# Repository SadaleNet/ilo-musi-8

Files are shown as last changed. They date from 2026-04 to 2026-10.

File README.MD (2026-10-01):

**(English: Scroll down for English | toki ike Inli li lon anpa pi toki pona)**

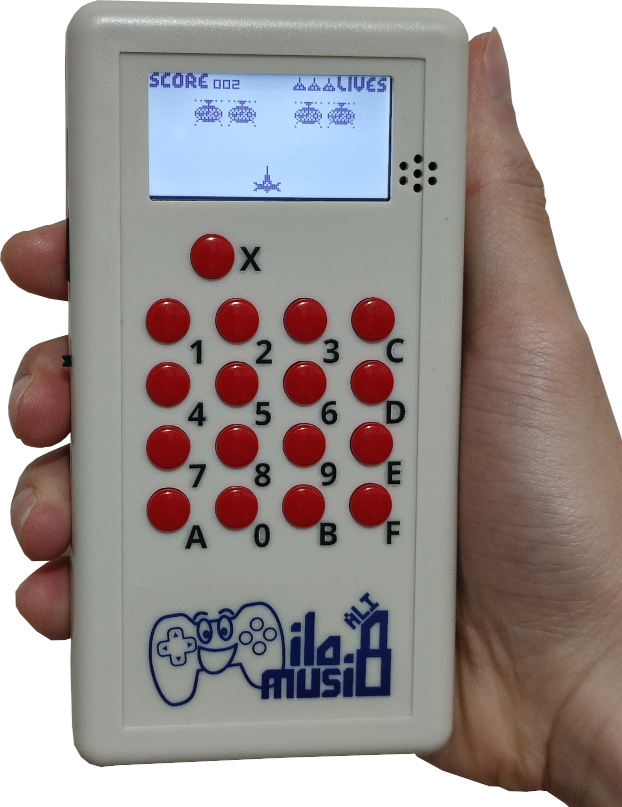
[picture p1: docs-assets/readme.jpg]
sitelen pi ilo musi 8


* lipu: https://ilomusi8.sadale.net/
* sitelen tawa lon ilo Jutu "Youtube": (TODO: tenpo ni la ona li lon ala. o awen a!)

# ilo musi 8 - ilo musi pi nasin CHIP-8

kepeken ilo musi 8 (ilo musi ali) la sina ken musi e musi CHIP-8. ilo musi 8 la:

* nasin CHIP-8 ni li ken:
	* nasin CHIP-8 (VIP) li ken
	* nasin SuperCHIP li ken
	* nasin XO-CHIP li ken lili. ni li ken ala: toki `plane n` (kule) en ma sona >= 4096. ali ante li ken
* tenpo pali: 5400 ips (90 instructions/frame)
* nena: nena CHIP-8 ali li lon (0-9, A-F). nena namako X kin li lon
* suli poki: 135x70x24mm
* wawa: poki wawa AAx2 anu linja wawa "USB MicroB"
* sona musi: kepeken lipu sona "TF Card"
	* nasin FAT16 en nasin FAT32 taso (o kepeken ala nasin exFAT!)
	* [nasin nimi "8.3 filename"](https://en.wikipedia.org/wiki/8.3_filename) taso
	* sina kin li ken pana e sona sin tawa ilo musi 8 kepeken lipu sona "TF Card"
* musi open li lon. sina pana e wawa tawa ilo musi 8 sina la sina ken lukin e sitelen pi wile sina
* toki mute li lon: toki pona (sitelen Lasin en sitelen pona) en [sitelen Sate](https://sadale.net/tok/sitelen-sate) en toki ike Inli
* sona ali ona li lon. jan ali li ken lukin e ona li ken ante e ona li ken pali e ona
* jan li ken pali e ona mute kepeken mani lili kepeken tenpo lili (sina pali e ona mute "20" la sina o pana e mani "$12x20" o kepeken tenpo "30minutesx20")
* jan li ken ante e lukin ona (jan li ken ante e musi open. jan li ken ante e sitelen lon selo.)

## sona seme li lon?

```
assembly/        # lon ma ni la sina kama sona e nasin pali pi ilo musi 8
bootloader/      # kepeken sona ni la sina ken pana e sona sin tawa ilo musi 8. ona li kama sona tan ILOMUSI8.BIN lon lipu sona
docs-assets/     # sitelen pi lipu README.MD
enclosure/       # sitelen pi lupa selo
firmware/        # kepeken sona ni la ilo musi 8 li pali. sina ken musi kepeken ilo musi 8 tan ni: sona ni li lon
kicad/           # lipu kiwen sona. ilo musi 8 li jo e lipu kiwen. jan li pana e sona tawa ona la ilo musi 8 li ken pali
label/           # sitelen selo en sitelen poki
manual/          # jan li lukin e ona la jan ni li kama sona e ilo musi 8 li ken musi kepeken ona
```

## o esun e ilo ni!

sina ken esun e ona lon [esun Sate](https://esun.sadale.net/)!

mi jo e mani namako la mi wile pana e ilo musi 8 tawa jan pi mani ala. :)

## o pali e ilo ni!

o lukin e lipu ni: "[assembly/](./assembly/)"

## ken

lipu anpa ni li mi ala. sina wile lukin e ken ona la o lukin e nimi insa ona:

* ./bootloader/linker_script
* ./bootloader/pff3a
* ./firmware/fatfs

mi pali e lipu ante ali. ken ona li ken "BSD 2-clause".

# ilo musi 8 - Handheld CHIP-8 Game Console

ilo musi 8 is a production-ready handheld CHIP-8 game console. Feature list:

* CHIP-8 Compatibility:
	* CHIP-8 (VIP): Full support
	* SuperCHIP: Full support
	* XO-CHIP: Partial support. No support for `plane n` (color mode) and memory beyond 4K. Everything else (e.g. audio) is fully supported
* Performance: 5400 ips (90 instructions/frame)
* Buttons: Full CHIP-8 button support (0-9, A-F), with an extra X key for escaping
* Dimensions: 135x70x24mm
* Power: AAx2 or USB MicroB
* Game Storage: TF card
	* Supports FAT16 and FAT32 (No support for exFAT)
	* Supports [8.3 filename](https://en.wikipedia.org/wiki/8.3_filename) only
	* Firmware update is supported via the card
* Bootrom support. Can be used for showing boot screen upon powering on of the device
* Multi-language UI: English, [Toki Pona](https://en.wikipedia.org/wiki/Toki_Pona) and [Sadalian Script](https://sadale.net/en/sadalian)
* Fully open source, including electronics, enclosure and firmware, with full BOM and assembly instruction.
* Optimized for small scale production in terms of material cost and box build assembly time (At batch of 20, it costs $12 and 30 minutes of assembly time per unit)
* Optimized for white-labeling (custom boot screen via the bootrom, custom branding sticker on enclosure, custom cardboard label, etc.)

## Repo Structure

```
assembly/        # Assembly instruction for you to build your own unit
bootloader/      # Bootloader for flashing the file "ILOMUSI8.BIN" on TF card as firmware
cardboard_label/ # Label slapped onto the packaging cardboard
docs-assets/     # Images for README.MD
enclosure/       # CNC hole-drilling diagram of an off-the-shelf enclosure
firmware/        # Firmware source code
kicad/           # Electronics design
label/           # Keycap labels and branding labels slapped onto the enclosure and cardboard label
manual/          # User manual source and PDF
```

## Ordering a unit

If you speak Toki Pona, it's available via [esun Sate](https://esun.sadale.net/). Please don't order there if you don't speak the language.

I'm also selling/gifting white-labeled units in a few other communities that I care about in small quantities.

This is a hobbyist project. It's all about sharing. Profit-making is not my objective. I intentionally limit my scale of operation to avoid burn out.
Currently I don't have a plan to sell it to the mass public and I'm not sure on if there's even a demand for that.

If you want a unit very badly, you can contact me and tell me your situation. I'll see if I could arrange something for you.

## Building your Own Unit

Please follow the the instruction in the "[assembly/](./assembly/)" folder

# License

This repo contains third-party source code. I do not claim the ownership of these third-party files. Please refer to the license file on the corresponding folders for their licenses:

* ./bootloader/linker_script
* ./bootloader/pff3a
* ./firmware/fatfs

For all other files, I made them. They're released under BSD 2-clause license.

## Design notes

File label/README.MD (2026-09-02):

**(English: Scroll down for English | toki ike Inli li lon anpa pi toki pona)**

# lipu sitelen pi ilo musi 8

lipu sitelen tu wan li lon:

* ima_brandlabel_50x25mm.png: o pana e sitelen ni tawa selo pi ilo musi 8!
* ima_keylabel_46.1x54.4mm.png: o pana e sitelen ni tawa selo pi ilo musi 8 lon poka nena ona!
* ima_cardboardlabel_a4.png: o pana e sitelen ni tawa poki pi ilo musi 8! suli ona li A4.

# Sticker Labels for ilo musi 8

This folder contains three sticker designs:

* ima_brandlabel_50x25mm.png: Branding label. Slap it onto the enclosure of ilo musi 8
* ima_keylabel_46.1x54.4mm.png: Key cap label with alignment marks. Slap it onto the enclosure of ilo musi 8
* ima_cardboardlabel_a4.png: Cardboard label. Print to an A4-sized sticker, cut it and slap it onto the cardboard packaging of ilo musi 8

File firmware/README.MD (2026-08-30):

**(English: Scroll down for English | toki ike Inli li lon anpa pi toki pona)**

# sona pi ilo musi 8

kepeken sona ni la ilo musi 8 li ken pali. sina ken pana e sona ni tawa ilo musi 8 kepeken nasin tu:

* nasin nanpa wan: o kepeken ilo `CH32FUN_PATH=/path/to/ch32fun make`. kin la sina ken kepeken ilo `minichlink` kepeken lipu `ilomusi8.bin`
* nasin nanpa tu: o pana e `ilomusi8.bin` tawa lipu sona "TF Card". o pana e lipu sona ni tawa ilo musi 8 sina. sina pana e wawa la sona pi ilo musi 8 li kama sona `ilomusi8.bin`

# Firmware of ilo musi 8

This is the firmware of ilo musi 8. You can flash it with the following means:

* Method 1: Run `CH32FUN_PATH=/path/to/ch32fun make`. Alternatively you can use `minichlink` to load the prebuilt binary `ilomusi8.bin` to your ilo musi 8 unit
* Method 2: Put the `ilomusi8.bin` to a TF card and insert it into your ilo musi 8 unit. Power it on and the bootloader would flash it

# Technical Documentation

(ni li ike suli. mi o kepeken ala toki pona!)

## To Build

Download [ch32fun](https://github.com/cnlohr/ch32fun/tree/master) separately.
Run `CH32FUN_PATH=/path/to/ch32fun make` to build.
It'd also perform flashing if you attached your ilo nena 8 via WCH-LinkE.

## Code FLASH Memory Layout

The 62kB Code FLASH area of the CH32V006 is partitioned into the following layout:

* 0x8000000 ~ 0x800DFFF (56kB): App
* 0x800E000 ~ 0x800E7FF (2kB): Global Config (e.g. buzzer volume, backlight, etc.)
* 0x800E800 ~ 0x800F7FF (4kB): BOOTROM, including its config

Since I'm using the linker script from the ch32fun upstream, I'm not overriding it.
Instead, the layout is implicitly enforced by ensuring that the app's flash size is below 56kB in the Makefile.

## Bulkmem Memory Sharing Mechanism

Since I'm running low on RAM and I'd like to ensure that `chip8.c` and `chip8.h` can be self-contained,
I'm doing something clever (and not-so-obvious) to use the CHIP-8 emulator's main memory area for something else while the emulator isn't running.
Please refer to `bulkmem.h` on how it works.

## DMA Allocation

The following DMA channels are used:

* Very high priority: SPI RX, DMA channel 2. Used by the TF Card operation `rcvr_mmc_with_crc()`.
* High Priority: Buzzer Timer (TIM3), DMA channel 4. Triggering rate depends on the pitch.
* Medium Priority: Button ADC, DMA channel 1. Triggered for each row scan.
* Low Priority: SPI TX, DMA channel 3. Used by the lcd operation `lcd_transfer_next_row()`, and the TF Card operations `xmit_mmc_with_crc()` and `rcvr_mmc_with_crc()`.

## ISR Allocation

The follow ISR handlers has been configured:

* Highest priority (0x00): Button ADC (DMA1_Channel1_IRQHandler). Triggered upon completion of row scanning
* Second highest priority (0x80): SPI TX for LCD (DMA1_Channel3_IRQHandler). Triggered upon completion of transfer of an LCD data row

The MCU supports two levels of preemption and the ADC interrupt handler is configured to be able to preempt the LCD interrupt handler.

## SPI Sharing

The SPI peripheral is shared between TF card and the LCD as follows:

* SPI_SCK - shared
* SPI_MOSI - shared
* SPI_MISO - for TF card only
* CARD_CS - for TF card only
* LCD_CS - for LCD only

Upon insertion of the TF card, it uses an incompatible proprietary protocol with CARD_CS ignored. It must be switched to SPI mode as soon as possible to avoid LCD commands messing with the card.

This mechanism is handled in `file_loop()`, which gets called once in the main loop of `main()`.

## PWM Configuration

TIM1 is used for PWM with frequency of 400khz. The valid PWM value is 0~15 (0 is full off, 15 is full on, 1~14 is anything in between).

It's used for LCD backlight adjustment and the buzzer volume adjustment.

* Initialization function: See `tim1_pwm_init()`
* LCD backlight adjustment: See `lcd_set_brightness()`
* Buzzer volume adjustment: See `buzzer_reload_dma_buffer()`. The volume (0-15) gets loaded to the DMA buffer, which's played by DMA1_Channel4.
	* For example, if the waveform is `[0,1,0,0,1,0,...]` and the volume is 15, the DMA buffer would be `[0,15,0,0,15,0,...]`
	* For the same waveform, if the volume is 8, the DMA buffer would become `[0,8,0,0,8,0,...]`

## CHIP-8 Emulator

The `chip8.c` and `chip8.h` are an implementation of CHIP-8 emulator. These two files are intentionally self-contained and does not make reference to any other files in this repo.

This way one could easily reuse the emulator in any other C codebases.

This is also the reason why the draw function `DXYN` does not share the draw functions in `draw.c`

## Crash Screen Documentation

In case the game's crashed, a crash screen would be shown. Here's the meaning of the crash screen:

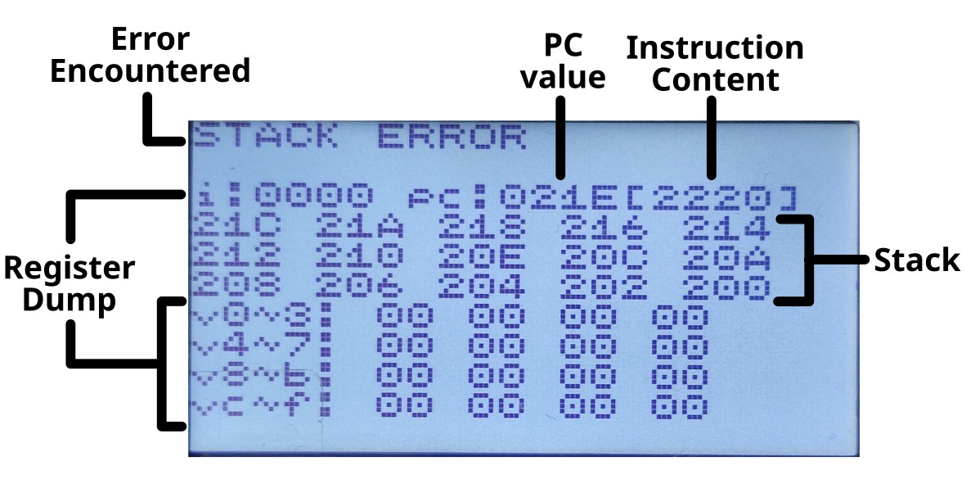
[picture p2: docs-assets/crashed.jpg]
Crash Screen Documentation


## Game Config INI Format Specification

Each game can have an INI file for specifying its configuration. The following fields can be specified:

| Field | Alias (in Toki Pona) | Datatype | Range | Description | Default Value |
| --- | --- | --- | --- |  --- | --- |
| quirks | nasin | HEXNUM | HEX x8 | For compatibility of ROM written for different CHIP-8 implementations. See `CHIP8_QUIRK_*` in chip8.h | 00000888 |
| speed | tenpo | DECNUM | 0~99 | Game speed. 0 is unlimited, 1~99 to set the speed limit (instruction/frame). Each frame is 60Hz. | 00 |
| audio | kalama | HEXBUF | HEX x32 | The audio buffer upon game launch. 1-bit. Sampling rate depends on the pitch. | F0F0F0F0F0F0F0F0F0F0F0F0F0F0F0F0 |
| pitch | wawa-kalama | DEC | 0~256 | The audio sampling rate upon game launch. Value is `4000*2^((X-64)/48)` Hz. | 64 |
| font | sitelen | HEXBUF | HEX x160 | The 4x5 font used in the game. | F0909090F02060202070F010F080F0F010F010F09090F01010F080F010F0F080F090F0F010204040F090F090F0F090F010F0F090F09090E090E090E0F0808080F0E0909090E0F080F080F0F080F08080 |
| font-large | sitelen-suli | HEXBUF | HEX x320 | The 8x10 font used in the game. | FFFFC3C3C3C3C3C3FFFF1878781818181818FFFFFFFF0303FFFFC0C0FFFFFFFF0303FFFF0303FFFFC3C3C3C3FFFF03030303FFFFC0C0FFFF0303FFFFFFFFC0C0FFFFC3C3FFFFFFFF0303060C18181818FFFFC3C3FFFFC3C3FFFFFFFFC3C3FFFF0303FFFF7EFFC3C3C3FFFFC3C3C3FCFCC3C3FCFCC3C3FCFC3CFFC3C0C0C0C0C3FF3CFCFEC3C3C3C3C3C3FEFCFFFFC0C0FFFFC0C0FFFFFFFFC0C0FFFFC0C0C0C0 |
| layout | ma-nena | DECNUM | 0~2 | Keypad layout. Shown before the game's launched. See `enum chip8_input_layout` in chip8.h | 0 |
| navigation | nena-tawa | HEXFLAG | HEX x(0~16) | The in-game buttons used for navigation. Shown before the game's launched. | (empty) |
| action | nena-pali | HEXFLAG | HEX x(0~16) | The in-game buttons used for action. Shown before the game's launched. | (empty) |
| replay | nena-sin | HEXFLAG | HEX x(0~16) | The in-game buttons used for replay or for starting the game. Shown before the game's launched. | (empty) |

Only the quirks and speed can be modified via the game config screen in the console. All other values must be modified by direct modification of the INI file.

Full Example:

```
quirks = 00002413
speed = 30
audio = FFFFFF00FFFFFF00FFFFFF00FFFFFF00
pitch = 16
font = 60A0A0A0C040C04040E0C0204080E0C0204020C020A0E02020E080C020C04080C0A040E02060404040A040A04040A060204040A0E0A0A0C0A0C0A0C06080808060C0A0A0A0C0E080C080E0E080C08080
font-large = 7CC6CEDED6F6E6C67C001030F03030303030FC0078CCCC0C183060CCFC0078CC0C0C380C0CCC78000C1C3C6CCCFE0C0C1E00FCC0C0C0F80C0CCC78003860C0C0F8CCCCCC7800FEC6C6060C183030300078CCCCEC78DCCCCC78007CC6C6C67C18183070003078CCCCCCFCCCCCCC00FC6666667C666666FC003C66C6C0C0C0C6663C00F86C66666666666CF800FE6260647C646062FE00FE6662647C646060F000
layout = 1
navigation = 5789
action = 6
replay = F
```

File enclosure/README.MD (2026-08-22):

**(English: Scroll down for English | toki ike Inli li lon anpa pi toki pona)**

# sitelen selo ni li seme?

* ilo musi 8 li kepeken selo "135x70x24". sina ken esun e selo ni tan jan mute. taso lupa li lon ala
* sitelen ni li sitelen lupa selo pi ilo nena 8
* sitelen ni li jo e toki Sonko tan ni: jan Sonko li wile lukin e sitelen ni

# What's this enclosure diagram?

* ilo musi 8 uses a generic "135x70x24" enclosure. However, this enclosure does not have any holes on it
* The files in this folder contains the dimension information of the holes on the upper lid so that the vendor can drill the holes
* The annotations are intentionally written in Chinese because I'm sending the design to Chinese vendor

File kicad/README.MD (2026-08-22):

**(English: Scroll down for English | toki ike Inli li lon anpa pi toki pona)**

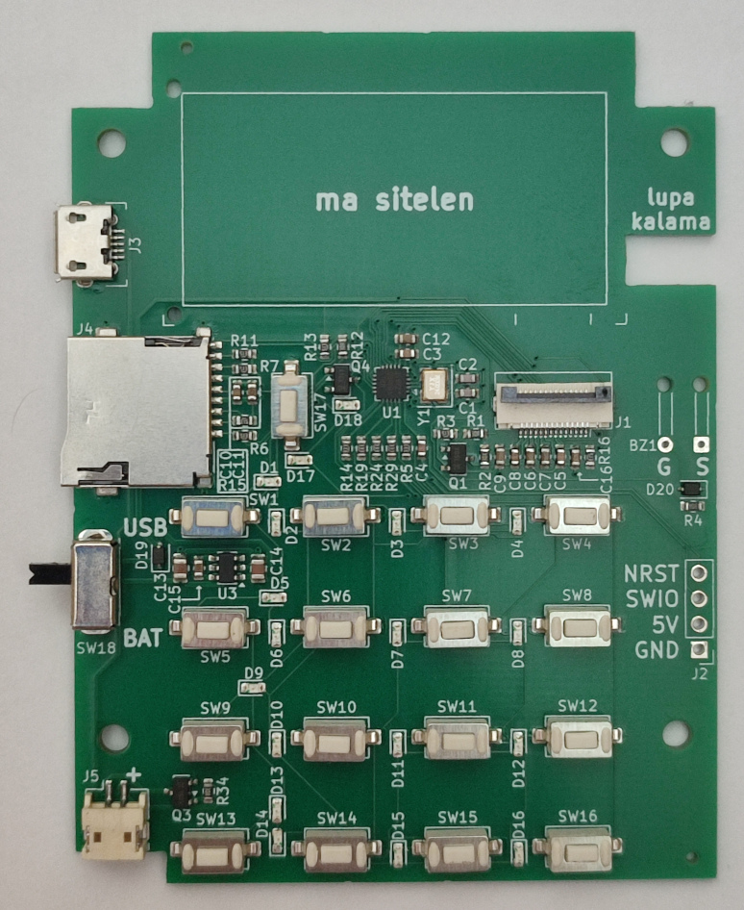
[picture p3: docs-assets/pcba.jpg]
lipu kiwen sona pi ilo musi 8


# lipu kiwen sona

ma ni li jo e sona pi lipu kiwen. mi pali e ona kepeken ilo "KiCad" en ilo lili "[Fabrication-Toolkit](https://github.com/bennymeg/Fabrication-Toolkit)".

sina ken esun e lipu kiwen sona kepeken nasin ni:

1. o open e lipu `ilomusiali-production.zip`
2. insa lipu `ilomusiali-production.zip` la o pana e ni tawa tomo pali: lipu `ilomusiali.zip` li lipu "gerber". lipu `bom.csv` en lipu `positions.csv` li lipu "SMT". mi kepeken tomo pali "JLCPCB".
3. o pana e mani tawa tomo pali. ni la sina o awen. lipu kiwen sona li jo e ijo mute. taso ilo sitelen en ilo kalama li lon ala.
4. o sona e ni: ilo kalama en ilo sitelen li lon ala. o pana e ona kepeken nasin insa [ma ni](../assembly/).

# PCBA Source and Production Files

This folder contains the source and production files for the PCBA. It uses KiCad with production files generated with the plugin "[Fabrication-Toolkit](https://github.com/bennymeg/Fabrication-Toolkit)".

To order PCBA on your own:

1. Extract `ilomusiali-production.zip`
2. Inside the extracted files, send `ilomusiali.zip` as gerber. `bom.csv` and `positions.csv` as SMT files. I used JLCPCB for the PCBA.
3. Pay up and wait for delivery. The PCBA has all electronic parts except for the screen and the buzzer, which you need to put that on your own.
4. Please notice that the buzzer and LCD aren't included. You need to put it on on your own as shown in the [assembly instruction here](../assembly/)

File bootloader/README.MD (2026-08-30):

**(English: Scroll down for English | toki ike Inli li lon anpa pi toki pona)**

# ilo "Bootloader" li seme?

* kepeken ilo ni la jan li ken pana e sona sin tawa ilo musi 8 kepeken lipu sona "TF Card"
* lipu sona li jo e lipu `ILOMUSI8.BIN` la ilo ni li wile pana e sona tawa ilo musi 8 kepeken ijo insa `ILOMUSI8.BIN`
* sina ken pana e ilo ni tawa ilo musi 8 kepeken ilo "WCH-LinkE". o kepeken nimi ni: `CH32FUN_PATH=/path/to/ch32fun make`
* kin la sina o kepeken nimi ni: `CH32FUN_PATH=/path/to/ch32fun make optionbytes`. sina kepeken ala nimi ni la ilo "Bootloader" li pali ala a!
* sina wile ala kepeken ilo `make` la sina kin li ken kepeken ilo `minichlink` kepeken `bootloader.bin`

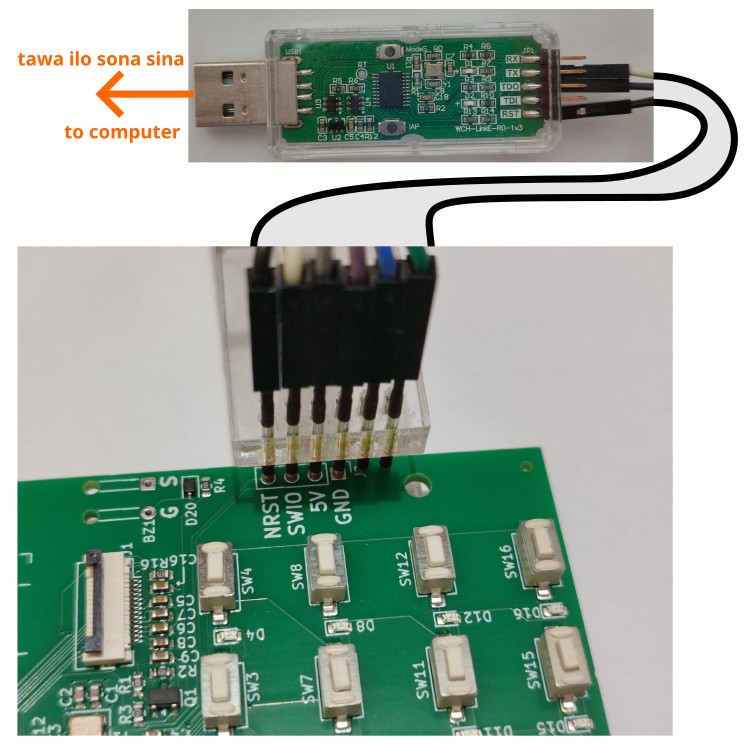
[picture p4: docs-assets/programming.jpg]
nasin pi pana sona


## sitelen pi ilo "Bootloader" li seme?

nimi `:)` li lon la ali li pona. nimi `:(` li lon la ijo li pakala.

sitelen namako li ike suli. o lukin e toki Inli lon anpa!

# Bootloader of ilo musi 8

* Provides mechanism of flashing firmware via TF Card
* Upon detecting `ILOMUSI8.BIN`, the bootloader would flash the file to Code FLASH
* To flash, WCH-LinkE is required. Run the following command after connecting ilo musi 8 with WCH-LinkE: `CH32FUN_PATH=/path/to/ch32fun make`
* You also need to enable the bootloader with the following command: `CH32FUN_PATH=/path/to/ch32fun make optionbytes`
* Instead of using make, you can flash the bootloader by using the pre-built binary `bootloader.bin` with `minichlink`

Programming Method

## Mechanism of Avoiding Re-entrance of Bootloader

The bootloader does not delete nor rename `ILOMUSI8.BIN`. It's the job of the main app to do that, which renames `ILOMUSI8.BIN` to `ILOMUSI8.BI_` upon success.

## Firmware Update Algorithm

Upon `ILOMUSI8.BIN` is detected, the bootloader performs the following:

For each sector (1024 bytes) of the Code FLASH:

1. Compare the difference between the `ILOMUSI8.BIN` and the Code FLASH
2. Flash the sector if there's any difference
3. After comparing all sectors, if any flashing had occurred, redo the entire procedure. The retry limit is 5 times.

## Meaning of the Bootloader Screen

Here's the meaning of the content shown on the screen:

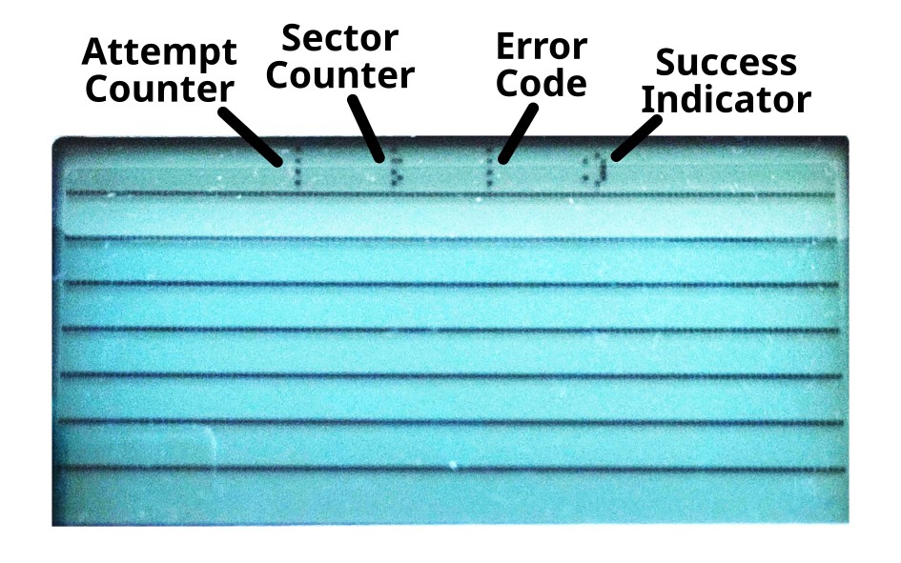
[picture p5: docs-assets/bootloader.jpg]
Bootloader Screen Documentation


* Attempt Counter: 0 means no flashing performed because the Code FLASH's unchanged. 1 means flashing performed once. 2 means flashing performed twice and so on.
* Sector Counter: The sector number of the current iteration attempt. Each sector is 1024 bytes.
* Error Code: The FatFs return code. 0 means OK. See https://elm-chan.org/fsw/ff/doc/rc.html for the full list
* Success Indicator: Shows `:)` upon success. `:(` upon failure, and `:` while update is in progress

Here's how to read the numbers above:

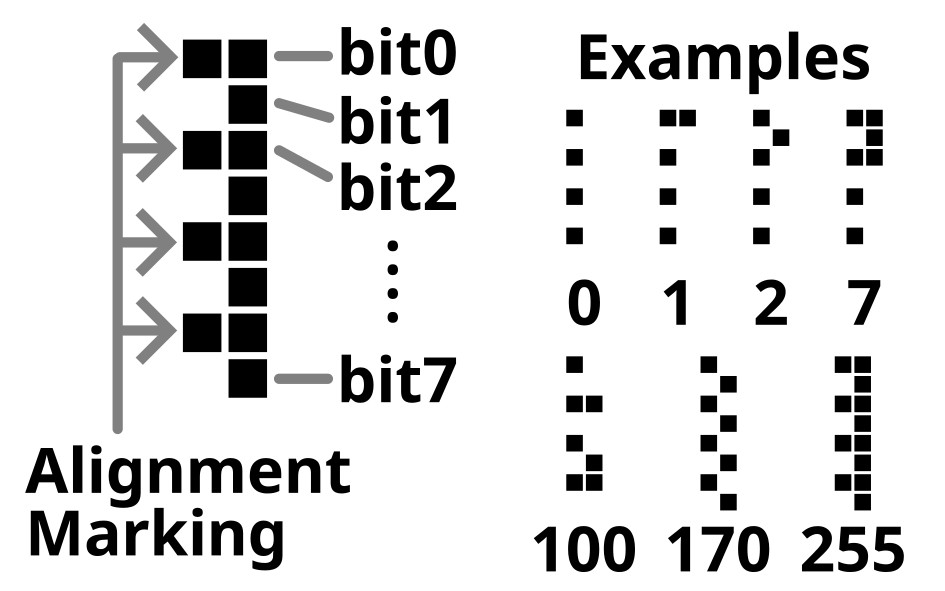
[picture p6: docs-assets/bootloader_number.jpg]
Number encoding scheme of the Bootloader


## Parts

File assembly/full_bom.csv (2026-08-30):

tomo esun | ijo | mani seme? | mani kulupu | suli kulupu | nanpa wile | mani USD pi ilo nena wan | pakala | mani USD pi pakala ala | mani pi poki tawa | mani USD pi poki tawa | linja esun | sona namako
Supplier | Item | Cost Unit | Cost of Batch | Batch Size | Quantity | USD per unit | Scrap Rate | USD per unit post-scrap | Shipping fee | USD shipping fee | URL | Remarks
JLCPCB | PCBA | USD | 105 | 20 | 1 | 5.25 | 0.10 | 5.833 | 9 | 9.00 | https://jlcpcb.com/ | Send them ilomusiali-production.zip. MOQ10@$7.2|MOQ20@$5.3|MOQ30@$4.5
兴华鑫蜂鸣器喇叭咪头 | Passive Piezo Buzzer with wire cylinder 13diax25mm | RMB | 0.3 | 1 | 1 | 0.05 | 0.05 | 0.049 | 4 | 0.62 | https://item.taobao.com/item.htm?id=742819220602&skuId=5122597596053
富邦胶带 | Buzzer Tape 10x10mm | RMB | 4.18 | 240 | 1 | 0.00 | 0.10 | 0.003 | 0 | 0.00 | https://item.taobao.com/item.htm?id=774299147776&skuId=5296126364706
深圳市尚视界科技 | SX12864-01-V01 LCD | RMB | 27.16 | 10 | 1 | 0.42 | 0.05 | 0.440 | 0 | 0.00 | https://item.taobao.com/item.htm?id=805726257321&skuId=5487106825036
亿达胶粘制品 | LCD Tape 20x20x1mm | RMB | 0.45 | 10 | 1 | 0.01 | 0.10 | 0.008 | 5 | 0.77 | https://item.taobao.com/item.htm?id=893302548160&skuId=5817595753109
佳睦电子仪表壳体 | Custom CNC Enclosure ABS 135x70x40mm | RMB | 280 | 20 | 1 | 2.15 | 0.05 | 2.267 | 9 | 1.38 | https://item.taobao.com/item.htm?id=604193389470&skuId=4405201651754 | Send them ilomusiali_techdraw.dxf and ilomusiali_techdraw.pdf
康宏电子品牌官方店 | Red Circular Keycap 7.5diax4.5mm pad 9.7dia | RMB | 10.6 | 100 | 17 | 0.28 | 0.05 | 0.292 | 6 | 0.92 | https://item.taobao.com/item.htm?id=753602071983&skuId=5626629278968
固万基五金科技 | M2.6x6 Pan-head 6mmdia Self-Tapping Philips Screw | RMB | 3.5 | 200 | 4 | 0.01 | 0.10 | 0.012 | 0 | 0.00 | https://item.taobao.com/item.htm?id=38979225704&skuId=4925331665948
固万基五金科技 | M2.5x10 Self-Tapping Philips Screw | RMB | 6.93 | 200 | 4 | 0.02 | 0.10 | 0.024 | 0 | 0.00 | https://item.taobao.com/item.htm?id=39009976141&skuId=5948766897484
深圳市科泽恩电子 | 2p black-red wire with ZH connector 50mm | RMB | 4.73 | 50 | 1 | 0.01 | 0.10 | 0.016 | 3 | 0.46 | https://item.taobao.com/item.htm?id=618175270348&skuId=4534398499147
博鑫弹簧企业店 | Battery spring pair semicircle 12x12mm | RMB | 13.6 | 100 | 1 | 0.02 | 0.10 | 0.023 | 0 | 0.00 | https://item.taobao.com/item.htm?id=659515501902&skuId=5013090193424
博鑫弹簧企业店 | Battery spring negative-positive connected 26.5x12mm | RMB | 13.6 | 100 | 1 | 0.02 | 0.10 | 0.023 | 0 | 0.00 | https://item.taobao.com/item.htm?id=659515501902&skuId=5013090193415
米乐奇兴伟峰兴专卖店 | Battery Tray Padding Tape 10x3mm | RMB | 8.8 | 10 | 0.1 | 0.01 | 0.20 | 0.017 | 0 | 0.00 | https://detail.tmall.com/item.htm?id=760991627406&skuId=6046450314907
小福水晶标厂 | Custom Keycap Label (UV DTF sticker) | RMB | 38 | 50 | 1 | 0.12 | 0.20 | 0.146 | 0 | 0.00 | https://item.taobao.com/item.htm?id=694929996955&skuId=5221531111683 | Send them ima_keylabel_46.1x54.4mm.png
星辰办公耗材店 | Custom Branding Label (standard sticker) | RMB | 60 | 100 | 1 | 0.09 | 0.10 | 0.103 | 0 | 0.00 | https://item.taobao.com/item.htm?id=680044670891&skuId=5045726682039 | Send them ima_brandlabel_50x25mm.png
(TBC) | Custom Cardboard Label | RMB | 25 | 50 | 1 | 0.08 | 0.10 | 0.085 | 0 | 0.00 | TBC | Exact cost of outsourcing TBC. I'm printing it with the printer in my home for now
海鑫优卡 专供批发 | TF Card | RMB | 3.3 | 1 | 1 | 0.51 | 0.10 | 0.564 | 6.8 | 1.05 | https://item.taobao.com/item.htm?id=620706685601
春诚百货 | TF Card to USB adapter | RMB | 0.77 | 1 | 1 | 0.12 | 0.10 | 0.132 | 3 | 0.46 | https://item.taobao.com/item.htm?id=704514415375&skuId=4980420817457
专正电子厂 | USB Micro-B Cable 100 wire strands 1meter | RMB | 0.58 | 1 | 1 | 0.09 | 0.15 | 0.105 | 4 | 0.62 | https://item.taobao.com/item.htm?id=575077271834&skuId=4873575713302
(TBC) | User manual | RMB | 25 | 50 | 1 | 0.08 | 0.10 | 0.085 | 0 | 0.00 | TBC | Exact cost of outsourcing TBC. I'm printing it with the printer in my home for now
chuanyue旗舰店 | Cardboard 150x100x40mm White | RMB | 11.96 | 50 | 1 | 0.04 | 0.15 | 0.043 | 0 | 0.00 | https://detail.tmall.com/item.htm?id=815987432269&skuId=5519165189919
- | Recycled Bubble Wrap | RMB | 0 | 1 | 1 | 0.00 | 0.00 | 0.000 | 0 | 0.00 | -
- | Office tape for holding the bubble wrap | HKD | 0.2 | 1 | 1 | 0.03 | 0.00 | 0.026 | 1 | 0.13 | -
图业包装 | Shipping bag 20x30cm | RMB | 6.5 | 100 | 1 | 0.01 | 0.10 | 0.011 | 0 | 0.00 | https://item.taobao.com/item.htm?id=614164738722&skuId=4492936382058
taobao official forwarding warehouse service | Shipping fee from mainland China warehouse to HKSAR | RMB | 0 | 1 | 0.11 | 0.00 | 0.00 | 0.000 | 30 | 4.62 | -
安立信旗舰店 | Lead-free soldering coil | RMB | 24.8 | 1 | 0.01 | 0.04 | 0.00 | 0.038 | 0 | 0.00 | https://detail.tmall.com/item.htm?id=588626885887&skuId=5970012670897
- | Electricity for soldering (says 0.1kWh) | HKD | 0.1 | 1 | 1 | 0.01 | 0.00 | 0.013 | 0 | 0.00 | -
- | mani ali (Total Cost) | USD | - | - | - | - | - | 10.36 | - | 20.02 | -
 |  |  |  |  |  |  |  | ^ mani pi ilo nena wan ^ |  | ^ mani pi poki tawa ^
 |  |  |  |  |  |  |  | ^ Total cost per unit ^ |  | ^ Shipping fee per batch ^

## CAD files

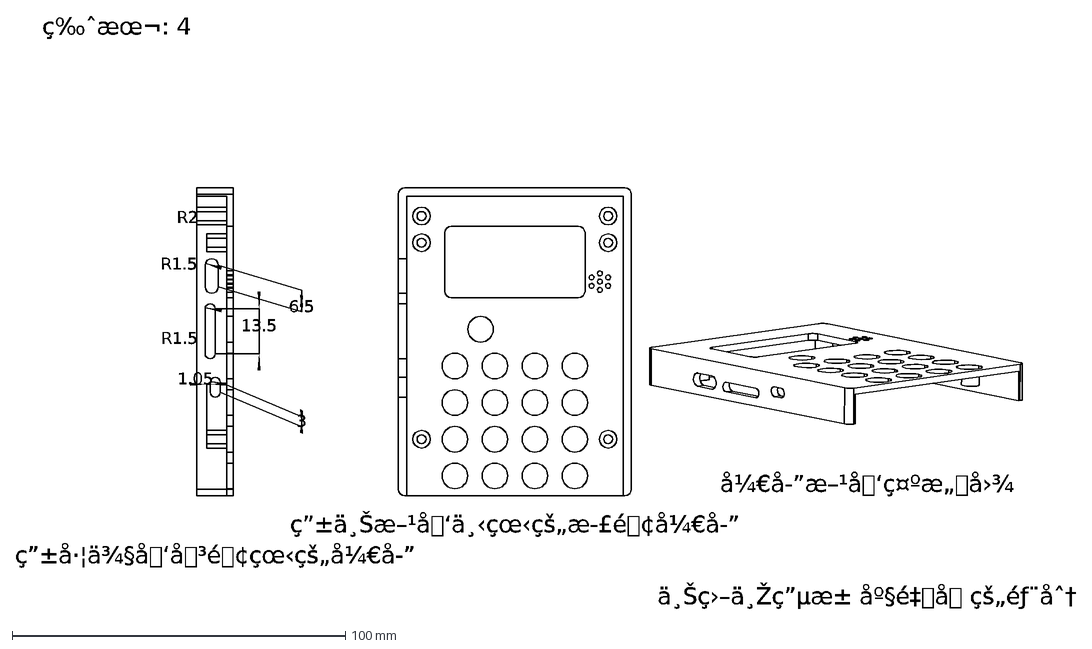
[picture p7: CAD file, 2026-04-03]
enclosure/ilomusiali_techdraw.dxf
ç‰ˆæœ¬: 4
3
13.5
6.5
R2
R1.5
1.05

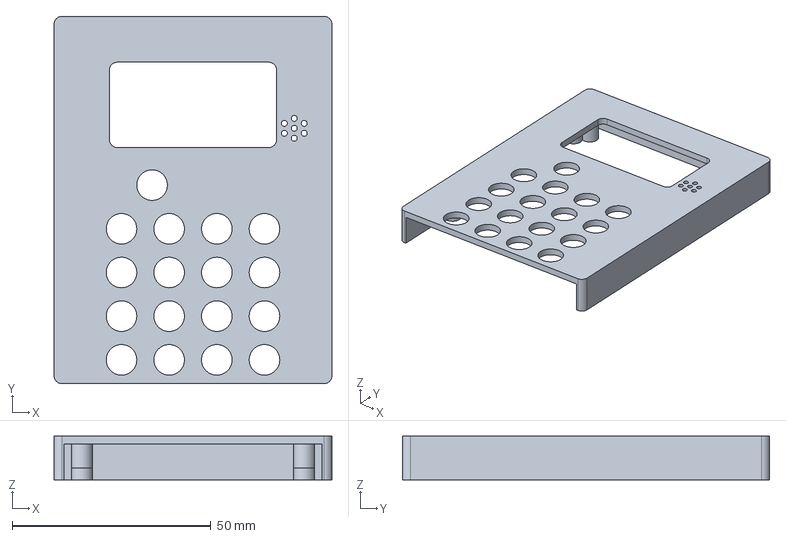
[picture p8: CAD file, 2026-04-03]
enclosure/ilomusiali.FCStd
70.0 x 92.5 x 11.0 mm

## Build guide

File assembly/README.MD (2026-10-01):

**(English: Scroll down for English | toki ike Inli li lon anpa pi toki pona)**

# o pali e ilo musi 8!

sina wile pali e ilo musi 8 la o kepeken nasin ni:

# o esun e ali!

o lukin e lipu [`full_bom.csv`](./full_bom.csv) li esun e ali pi ilo musi 8.

# lipu kiwen sona

## lipu kiwen sona: o pana e ilo kalama!

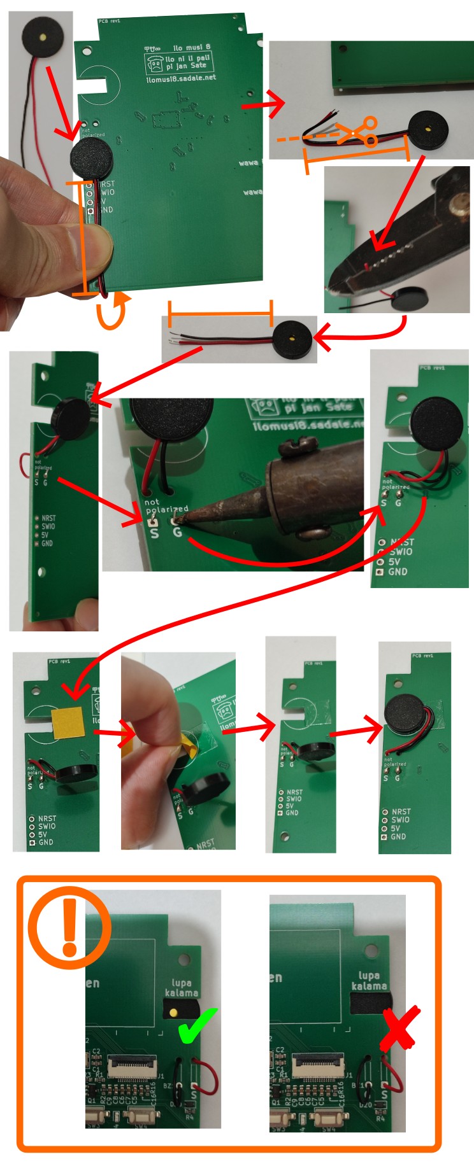
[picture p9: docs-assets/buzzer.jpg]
nasin pana pi ilo kalama


## lipu kiwen sona: o pana e ilo sitelen!

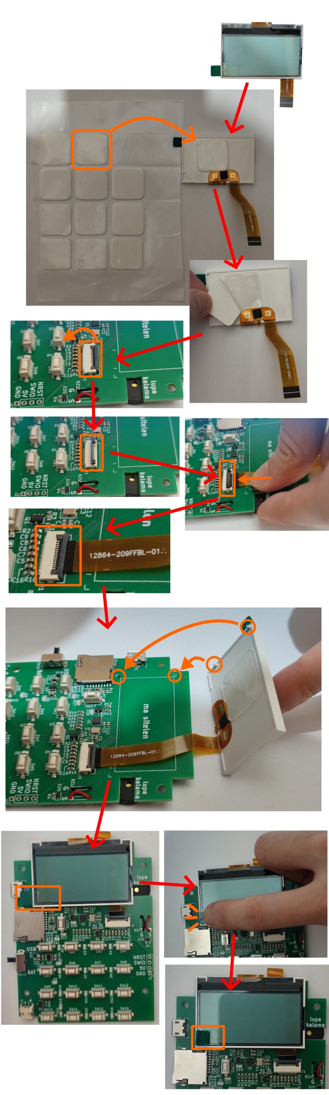
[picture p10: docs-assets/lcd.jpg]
nasin pana pi ilo sitelen


## lipu kiwen sona: o pana e sona!

nasin pi pana sona

* o kepeken ilo "WCH-LinkE" sama sitelen sewi ni. ni la o pana e nimi ni tawa ilo sona sina:

```
export CH32FUN_PATH=/path/to/ch32fun  # https://github.com/cnlohr/ch32fun
cd /path/to/ilo-musi-8/bootloader/
make
make optionbytes
cd /path/to/ilo-musi-8/firmware/
make
```

# selo

## selo: o pana e sitelen nena e nena e lipu kiwen sona!

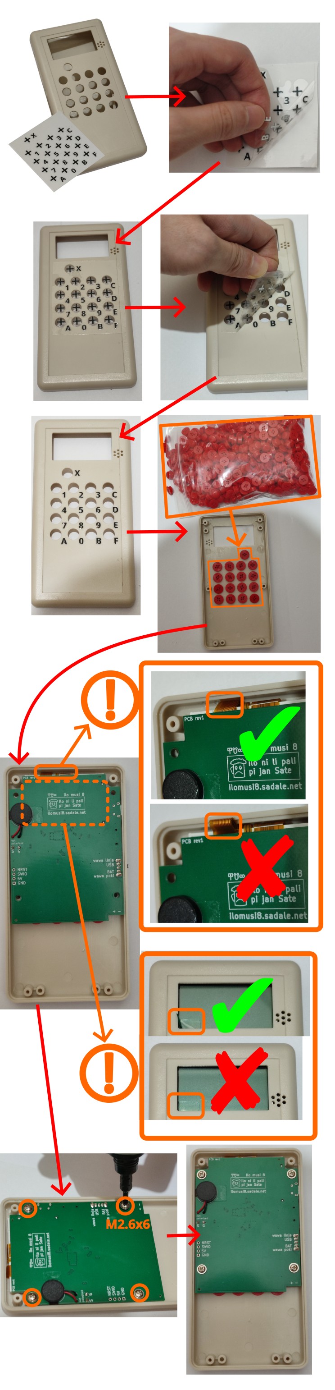
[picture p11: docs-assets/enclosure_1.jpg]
nasin pana pi sitelen nena en nena en lipu kiwen sona


## selo: o pali e ijo pi poki wawa! o wan e poki!

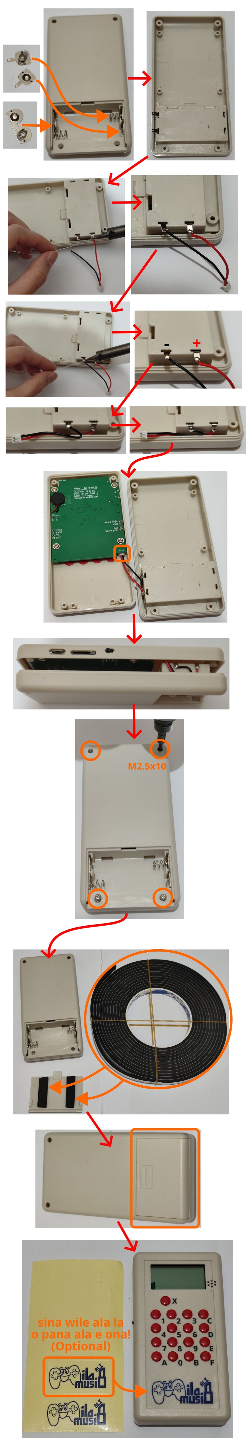
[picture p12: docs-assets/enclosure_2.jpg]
nasin pana pi sitelen nena pi nena pi lipu kiwen sona


# o lukin e pakala!

1. o pana e poki wawa "AAx2" tawa ilo musi 8. taso o pana ala e wawa e lipu sona "TF Card" tawa ona
2. o pilin awen e nena "D" e nena "E". ni la o pana e wawa
3. o pilin e nena "A". kalama musi li lon
4. o pilin e nena "B". suno pi ilo sitelen li weka. o pilin sin e nena "B". suno li kama sin
5. o pilin e nena "C". ilo sitelen li kama pimeja ala. o pilin sin e nena "C". ilo sitelen li kama pimeja ali
6. o pilin e nena "X"
7. o lukin e nanpa suli. nanpa ni li wawa "mV" pi ilo sona. nanpa "3250~3350" li pona
8. nena ali li jo e nanpa. sina pilin e nena lon tenpo wan la nanpa li kama wan. lon tenpo tu la nanpa li kama tu. nena ali la o pilin lon tenpo luka tu tu (9). nanpa ali li kama luka tu tu (9).
9. o weka e wawa. o pana e lipu sona "TF Card". musi o insa lipu sona ni.
10. o pana e wawa kepeken linja wawa "USB"
11. o lukin e ni: musi pi lipu sona li lon
12. o anu e ijo musi. sina pana e ijo sin tawa musi ni la pakala o lon ala!

# o poki e ali!

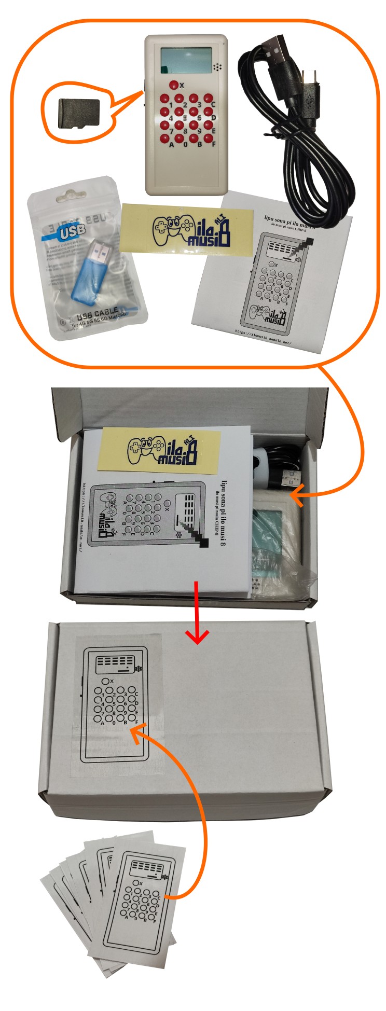
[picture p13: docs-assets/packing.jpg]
nasin poki pi ijo ali


# pini!

ni li pini. tenpo ni la sina jo e ilo musi 8 wan! :D

kepeken nasin ni la sina ken pali e ilo musi 8 pi mute "10~50".

sina wile pali e ilo musi 8 pi mute mute "100~200" la o ante e ona. ni la sina ken pali e ona kepeken mani lili.

# Building ilo musi 8 Unit(s)

This is the step-by-step instruction of assembling your own ilo musi 8 unit(s):

# Purchase Material

Please purchase all of the material in this BOM file: [`full_bom.csv`](./full_bom.csv)

# PCBA

The PCBA received from the factory isn't completed. Here's the post-processing steps required:

## PCBA: Putting on Buzzer

Instruction for Putting on Buzzer

## PCBA: Installing LCD

Instruction for Installing LCD

## PCBA: Programming

WCH-LinkE Connection

* Please connect "WCH-LinkE" as shown above and run the following commands on your computer:

```
export CH32FUN_PATH=/path/to/ch32fun  # https://github.com/cnlohr/ch32fun
cd /path/to/ilo-musi-8/bootloader/
make
make optionbytes
cd /path/to/ilo-musi-8/firmware/
make
```

# Enclosure

## Enclosure: Front Part

Assembly Instruction for the Front Part of the Enclosure

## Enclosure: Back Part

Assembly Instruction for the Back Part of the Enclosure

# Quality Control

1. Insert "AAx2" into the ilo musi 8 unit without powering it on for now. Do not insert TF card either.
2. Hold "D" and "E" and power it on to enter hardware test mode
3. Press "A". Make sure that there's audio clip being played
4. Press "B". Make sure that LCD backlight would turn off. Press "B" again. Make sure that it'd turn on again
5. Press "C". Make sure that the LCD display would be all pixel off. Press "C" again. Make sure that LCD display would be all pixel on. Pay attention to possible dead pixels
6. Press "X" to enter another page
7. Pay attention to the number shown on the top-right corner. That's the voltage of ilo musi 8 in unit of mV. Make sure that the displayed value is between "3250~3350"
8. The display shows the button press count of each button. Press each of the buttons 9 times and make sure that 9 would be displayed for each button. (To retest, after reaching 9, the counter would wrap to 0. If the counter of button X wraps, all numbers would be reset to 0)
9. Power off. Insert TF Card that's loaded with a game
10. Power it on with USB cable
11. Make sure that the game selection menu's shown
12. Select a game and modify game config and save it. Make sure that no error would be shown

# Pack Everything

Instruction of Packing Everything

# Done!

That's it! You've successfully built a unit of ilo musi 8. Build more if required! :D

This product is optimized for manufacturing with batch size of 10~50 and can be built at home.

For quantity above 100~200, I'd recommend modifying the design for further cost optimization (e.g. build PCBA test jig, order a custom mold for the enclosure, etc.)

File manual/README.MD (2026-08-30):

**(English: Scroll down for English | toki ike Inli li lon anpa pi toki pona)**

# lipu sona pi ilo musi 8

kepeken lipu sona ni la jan li sona e nasin kepeken pi ilo musi 8.

o pana e sitelen PDF ni tawa lipu A4! lipu ODT li tan pi lipu PDF.

# User Manual of ilo musi 8

Contains usage information of ilo musi 8 for the end-user.

The PDF file is meant to be printed on A4 paper. The ODT file is the source.

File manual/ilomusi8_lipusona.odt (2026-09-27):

lipu sona pi ilo musi 8

ilo musi pi nasin CHIP-8

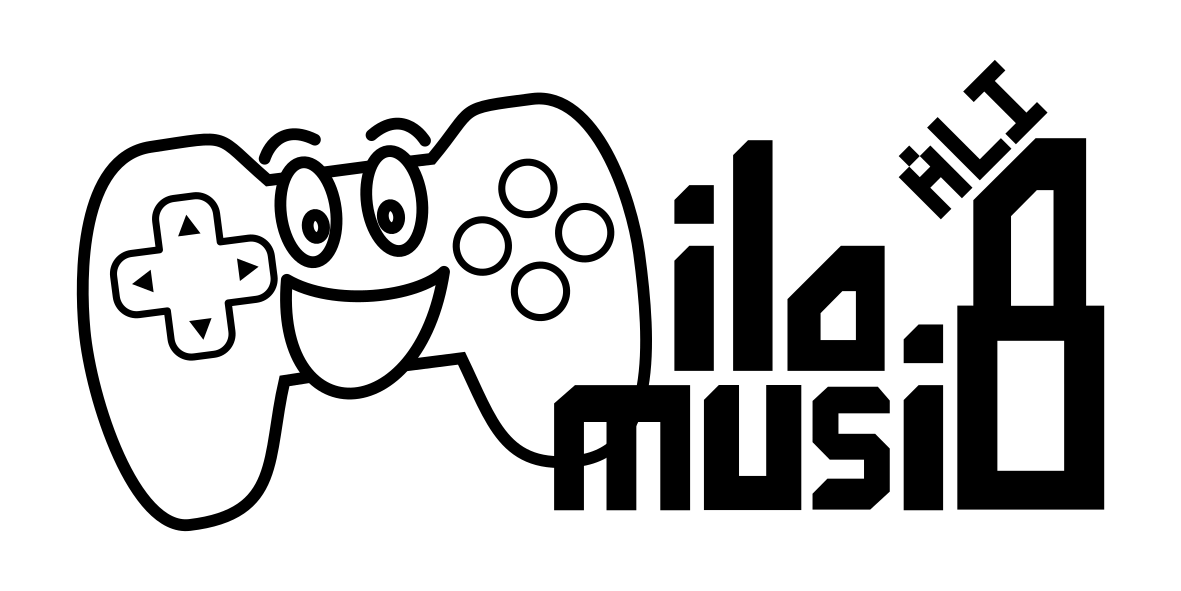
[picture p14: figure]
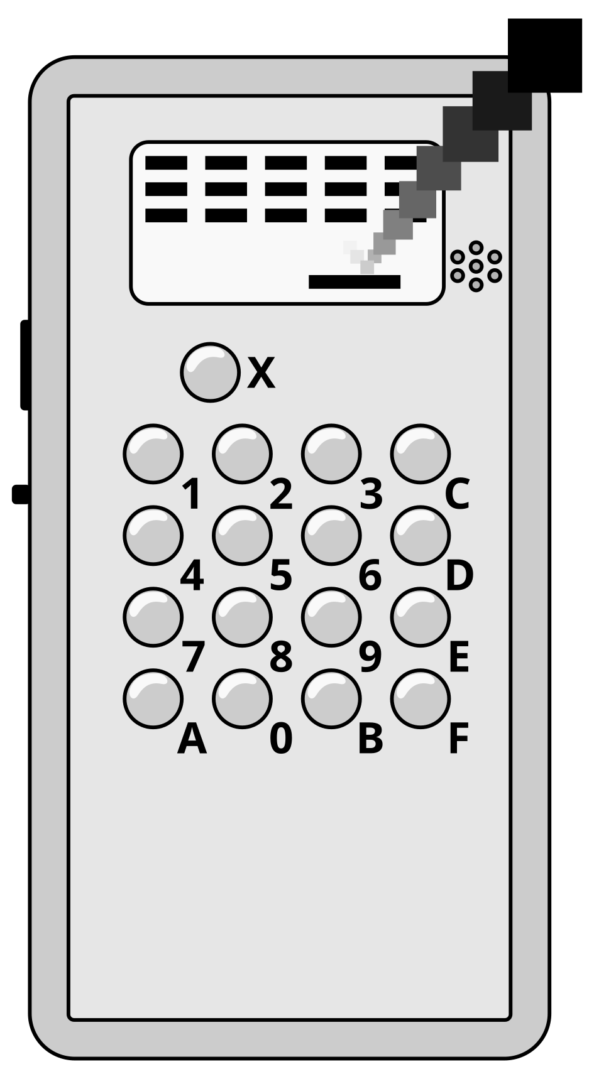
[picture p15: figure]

https://ilomusi8.sadale.net/

seme li lon?

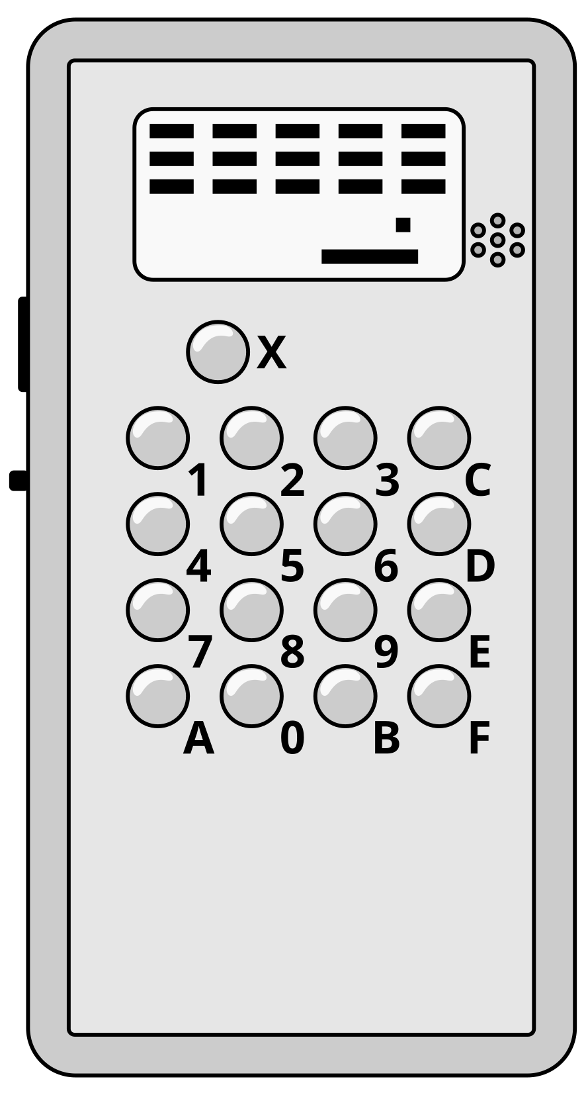
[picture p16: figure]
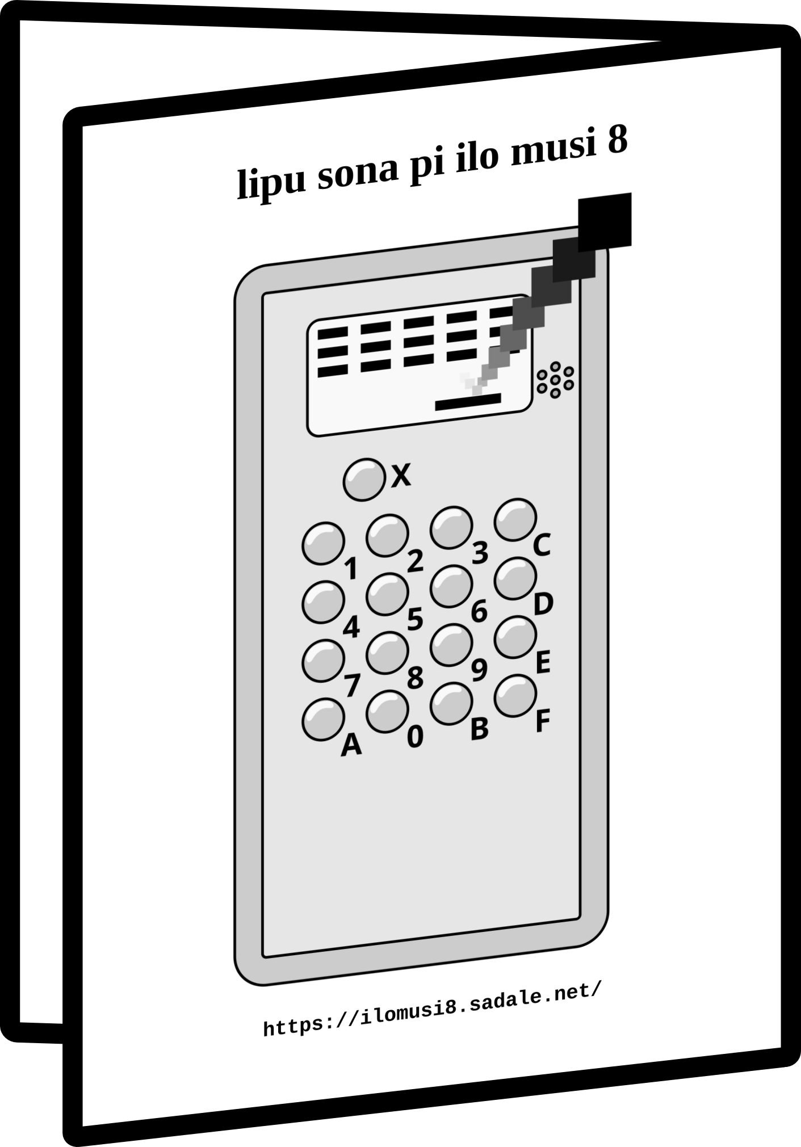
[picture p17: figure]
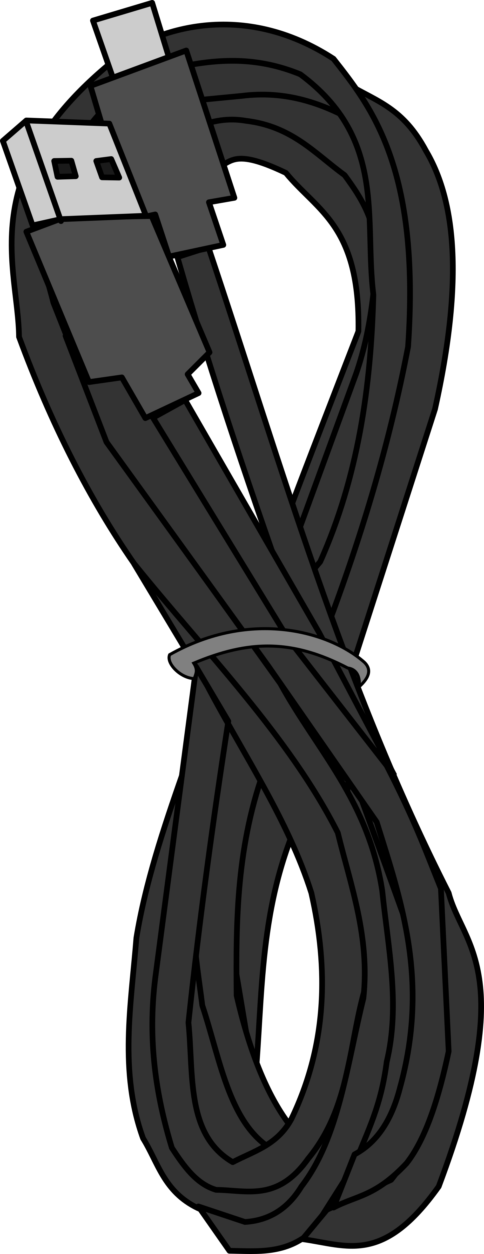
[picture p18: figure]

ilo musi 8 | lipu sona ni | linja wawa USB

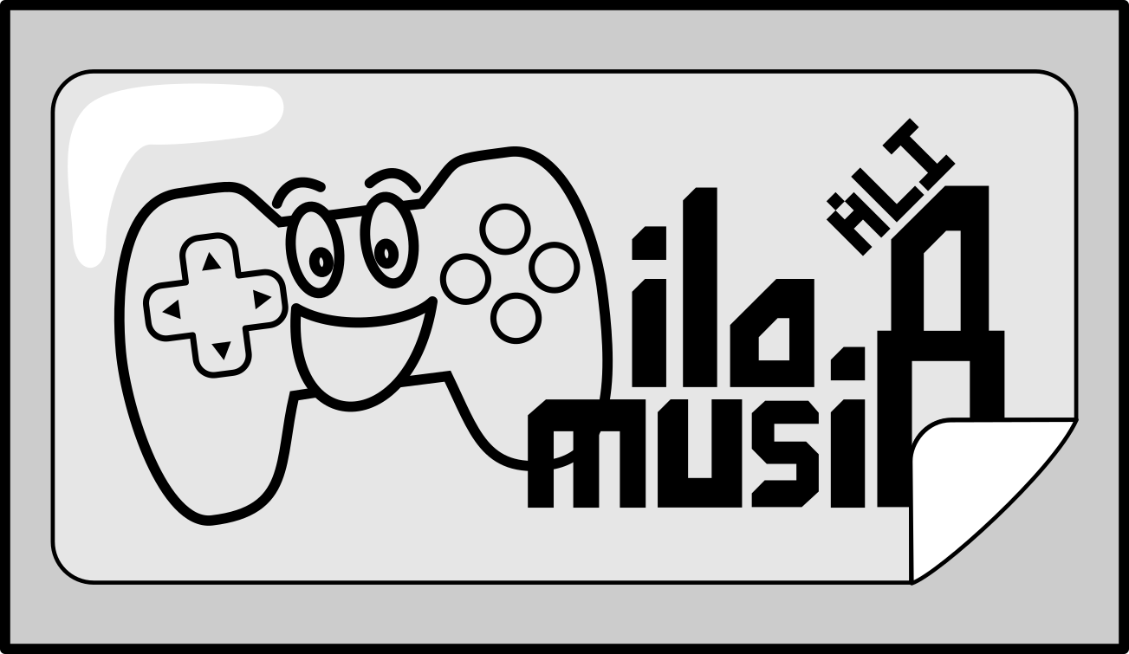
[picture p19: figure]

lipu sona TF (insa ilo musi 8) | ilo pi ante musi | lipu sitelen

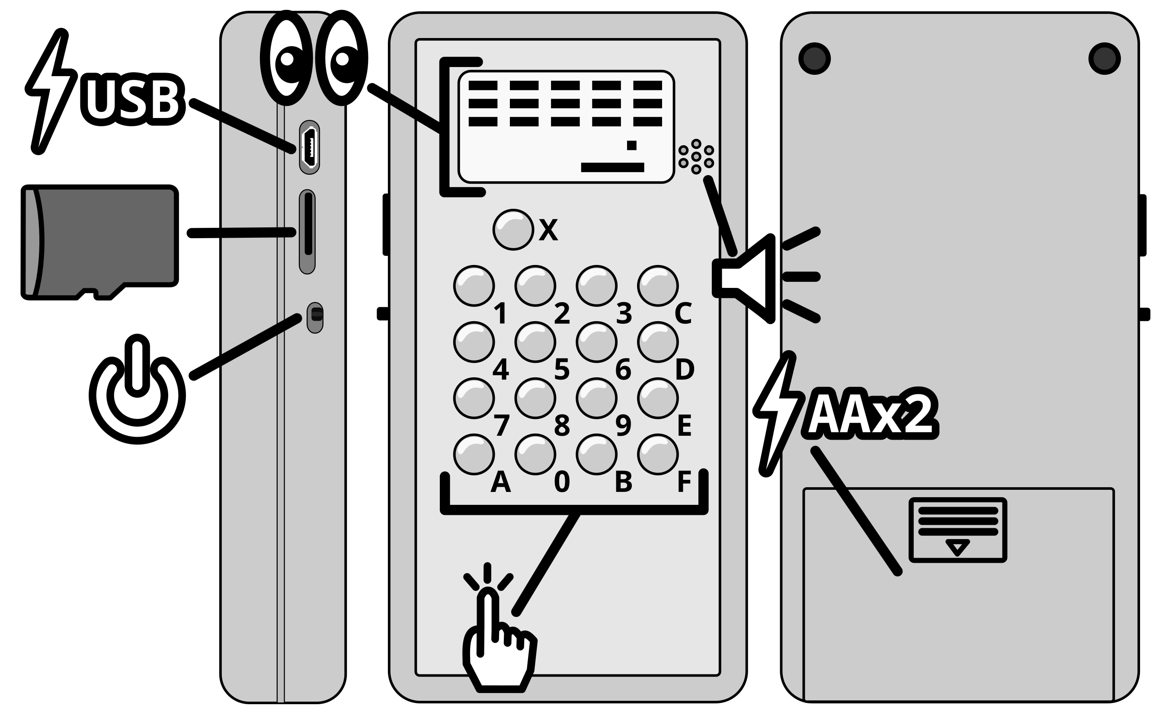
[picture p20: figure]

seme li ken?

- nasin CHIP-8 ali en nasin SuperCHIP ali
- nasin XO-CHIP (taso sona >4K en kule li ken ala)
- tenpo pali: 5400 ips (90 instructions/frame)
- musi li lon lipu sona TF (.CH8 li musi, .INI li ijo pi ante musi)
  - nasin pi lipu sona: FAT16 anu FAT32 (exFAT ala!)
  - nasin nimi: 8.3 filename
- musi open "BOOTROM" li lon. sina ken ante e ona
- toki mute li lon: toki Inli en toki pona en sitelen Sate

nasin kepeken

ma pi anu musi

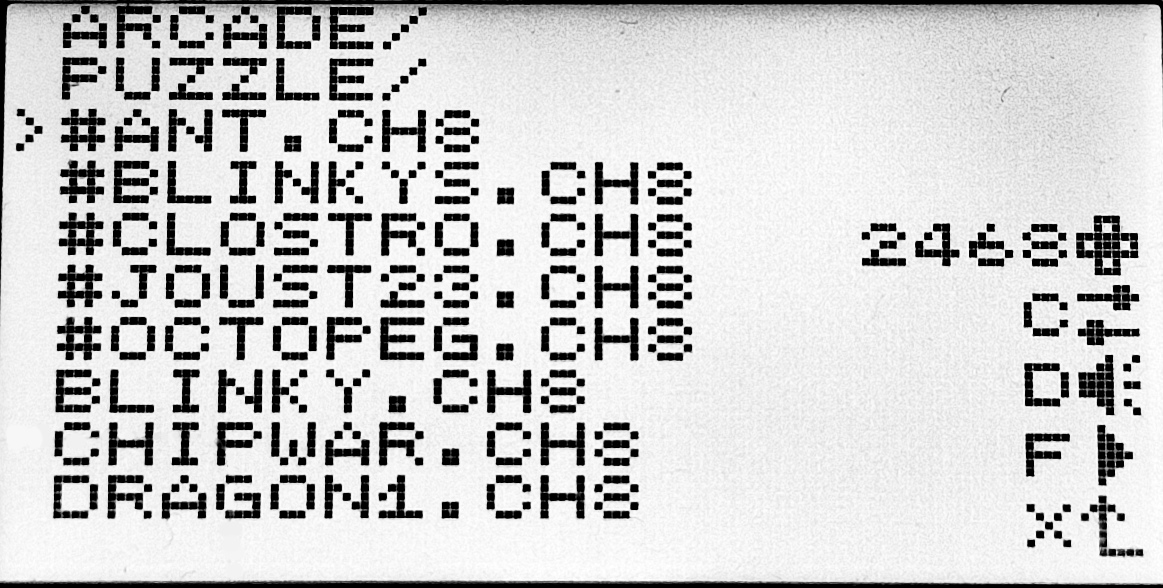
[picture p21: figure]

nimi mute | [.CH8] li lon la ona li musi [#] li lon la ona li musi pi pona mute. o musi e ona! [/] li lon la ona li poki. musi mute li ken insa ona
2468 | kepeken nena ni la sina ken tawa e nimi [>]
C | kepeken nena ni la sina ken ante e ijo pi musi [>]
D | kepeken nena ni la sina ken ante e ijo pi ilo musi 8
F | kepeken nena ni la sina musi e musi pi nimi [>] sina anu e poki la sina kama insa poki. sina insa musi la sina ken weka kepeken nena [X]
X | kepeken nena ni la sina weka tan poki

ma pi ante musi

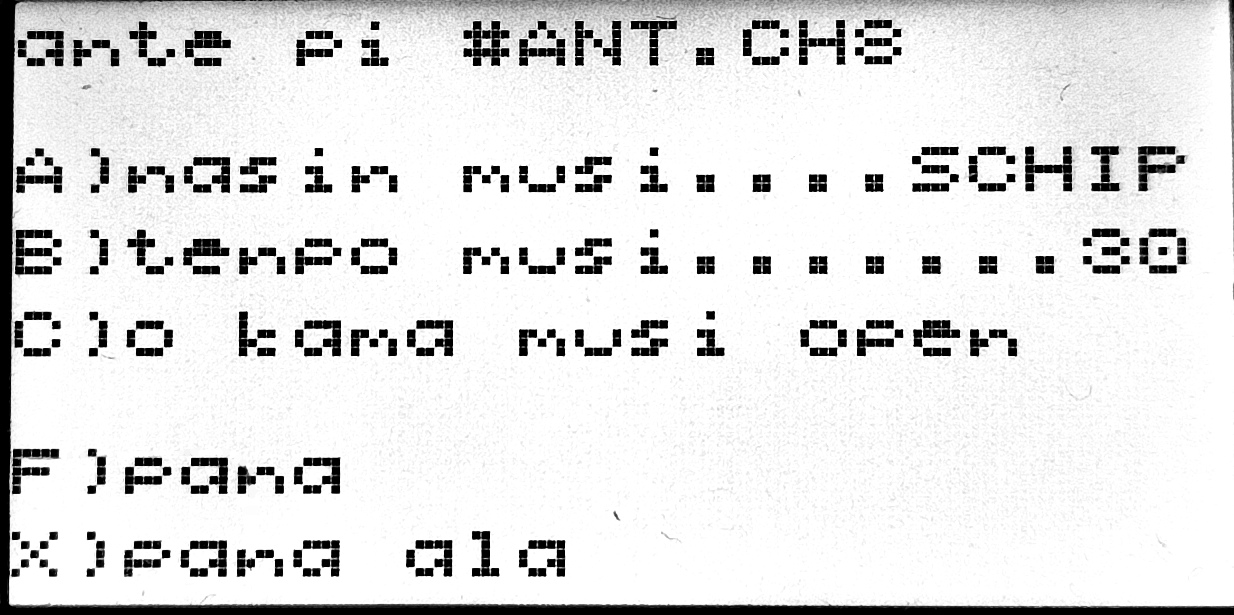
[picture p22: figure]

A | nasin musi ni li ken: VIP, SCHIP, OCTO, NANPA nasin NANPA la: bit 0: CHIP8_QUIRK_SHIFT bit 1: CHIP8_QUIRK_MEMORY_LEAVE_I_UNCHANGED bit 2: CHIP8_QUIRK_MEMORY_INCREASE_BY_X bit 3: CHIP8_QUIRK_WRAP bit 4: CHIP8_QUIRK_JUMP bit 5: CHIP8_QUIRK_VBLANK bit 6: CHIP8_QUIRK_LOGIC bit 7: CHIP8_QUIRK_LORES_WIDE_SPRITE bit 8: CHIP8_QUIRK_LORES_TALL_SPRITE bit 9: CHIP8_QUIRK_LORES_SCROLL_DIV2 bit 10: CHIP8_QUIRK_HIRES_COLLISION bit 11: CHIP8_QUIRK_RESIZE_CLEAR_SCREEN bit 12: CHIP8_QUIRK_VF_ORDER bit 13: CHIP8_QUIRK_FX1E_REPORT_OVERFLOW VIP = 00000060 | SCHIP = 00000413 | OCTO = 00000888
B | nanpa 01~99 la, nanpa suli la pali li mute kepeken tenpo lili. nanpa lili la pali li lili kepeken tenpo mute. nanpa 00 la, pali li mute mute kepeken tenpo lili
C | musi ni li kama musi open. ni la sina pana e wawa tawa ilo musi 8 la musi ni li kama lon
F X | o pana e ante sina kepeken nena [F]. nena [X] la ante ala

ma pi ante pi ilo musi 8

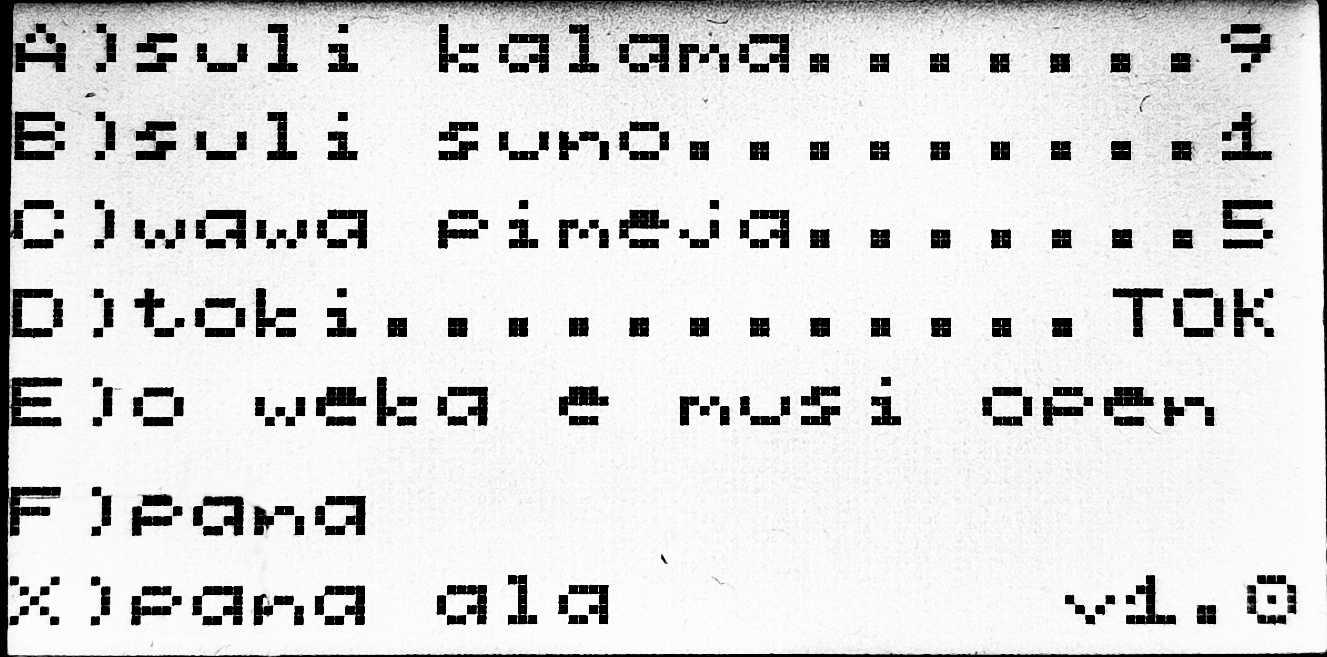
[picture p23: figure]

A | nanpa li suli la kalama li suli. nanpa li lili la kalama li lili. nanpa ni li ken: 0~9. nanpa pi ilo sin li ni: 9
B | nanpa li suli la suno pi ilo sitelen li kama wawa. nanpa li lili la suno pi ilo sitelen li kama lili. nanpa ni li ken: 0~9. nanpa pi ilo sin li ni: 1
C | nanpa li suli la ilo sitelen li kama pimeja. nanpa li lili la ilo sitelen li kama walo. nanpa ni li ken: 0~9. nanpa pi ilo sin li ni: 5
D | sina ken ante e toki. toki ni li lon: EN, TOK, sitelen pona, sitelen Sate toki pi ilo sin li ni: EN
E | ni li weka e musi open. musi open li weka la, sina pana e wawa tawa ilo musi 8 la, musi ala li lon. sina kama lon "ma pi anu musi"
F | o pana e ante sina kepeken nena ni
X | kepeken nena ni la ante sina li kama weka

sona sin

sina ken pana e sona sin tawa ilo musi 8 sina lon ma ni:

https://ilomusi8.sadale.net/sona-sin

musi sin

sina ken pana e musi sin tawa ilo musi 8 sina.

sina jo e musi CHIP-8 la, o ante e nimi ona. nimi ona o kama xxxxxxxx.CH8. ni la o pana e ona tawa lipu sona TF sina.

o kepeken nasin nimi "8.3 filename".

sina pana e lipu sona ni tawa ilo musi 8 sina la, o ante e musi ni kepeken nena [C]. ni la sina kama lon "ma pi ante musi" li ken pana e nasin pona tawa musi sin sina.

kin la sina ken pana e xxxxxxxx.INI tawa musi ni. nasin INI la o lukin e ma ni:

https://github.com/SadaleNet/ilo-musi-8/firmware/README.MD

sina ken kama jo e musi sin tan ma ni:

https://ilomusi8.sadale.net/musi-sin

sina kin li ken kama jo e musi sin tan ma ante.

********************

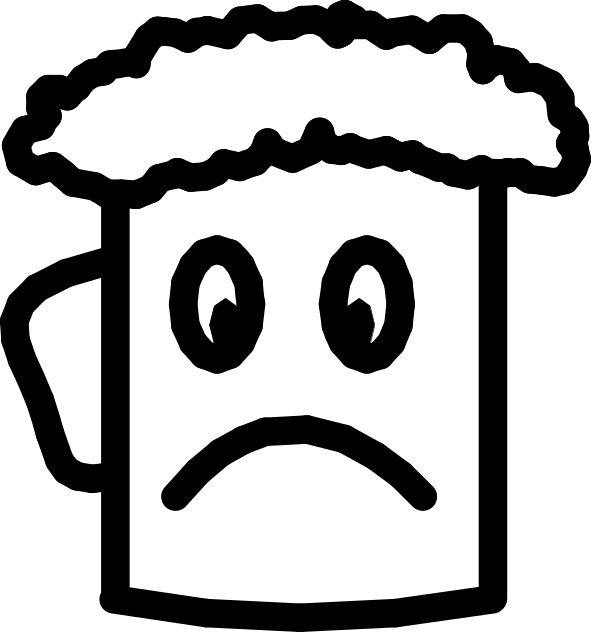
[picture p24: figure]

| ilo ni li pali pi jan Sate

https://sadale.net/tok/

User Manual of ilo musi 8

Handheld CHIP-8 Game Console

https://ilomusi8.sadale.net/

What's Inside?

ilo musi 8 Unit | User Manual | USB Power Cable
TF Card (pre-inserted) | TF Card Adapter | Enclosure Sticker

Feature

- Supports all CHIP-8 and SuperCHIP instructions
- Partial XO-CHIP support (4K memory and monochrome only)
- Performance: 5400 ips (90 instructions/frame)
- TF card for game rom storage (.CH8 for rom, .INI for config)
  - Filesystems: FAT16 or FAT32 (exFAT Unsupported!)
  - Filename Format: 8.3 filename
- BOOTROM support for customization of boot screen
- Multilanguage support: English, Toki Pona, Sadalian Script

Usage

Game Selection Menu

Game List | [.CH8] are game ROMs [#] are featured games. Highly recommended! [/] are folders
2468 | Menu navigation. Changes the position of [>]
C | Modify the config of the selected game
D | Modify the global config of the ilo musi 8 unit
F | For game ROM, launch the selected game. For folder, navigate into the folder. While you're in-game you can quit with [X]
X | Get out of the current folder

Game Config

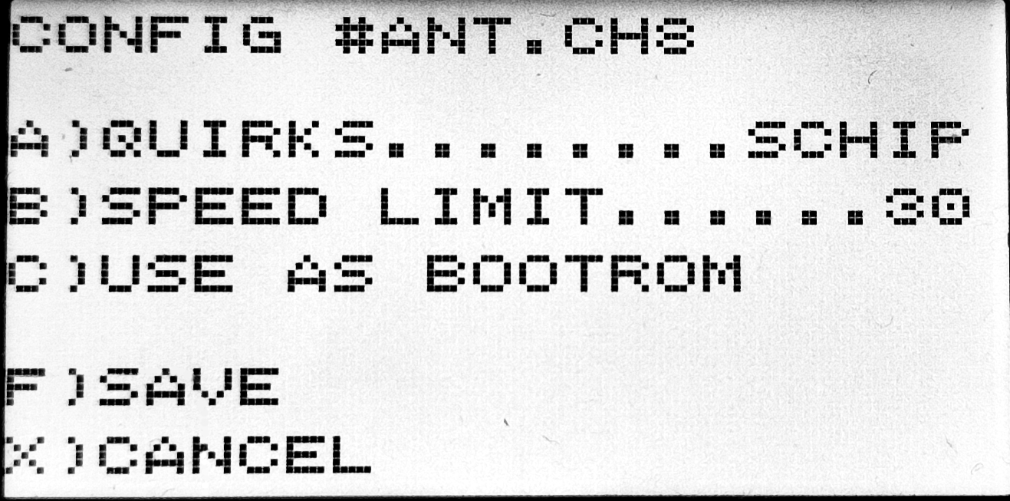
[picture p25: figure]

A | Each ROM requires different quirks to run. Options: VIP, SCHIP, OCTO, CUSTOM For CUSTOM: bit 0: CHIP8_QUIRK_SHIFT bit 1: CHIP8_QUIRK_MEMORY_LEAVE_I_UNCHANGED bit 2: CHIP8_QUIRK_MEMORY_INCREASE_BY_X bit 3: CHIP8_QUIRK_WRAP bit 4: CHIP8_QUIRK_JUMP bit 5: CHIP8_QUIRK_VBLANK bit 6: CHIP8_QUIRK_LOGIC bit 7: CHIP8_QUIRK_LORES_WIDE_SPRITE bit 8: CHIP8_QUIRK_LORES_TALL_SPRITE bit 9: CHIP8_QUIRK_LORES_SCROLL_DIV2 bit 10: CHIP8_QUIRK_HIRES_COLLISION bit 11: CHIP8_QUIRK_RESIZE_CLEAR_SCREEN bit 12: CHIP8_QUIRK_VF_ORDER bit 13: CHIP8_QUIRK_FX1E_REPORT_OVERFLOW VIP = 00000060 | SCHIP = 00000413 | OCTO = 0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
B | Some ROMs would only run properly with a speed limit. Set it to 01~99 to enforce a speed limit. Set it to 00 to run without speed limit. Unit is instructions per frame. Each frame is 60Hz
C | Use the current game as BOOTROM so that the game would start upon power on. Used for custom boot screen
F X | [F] to save, [X] to discard. No effect on BOOTROM

Global Config

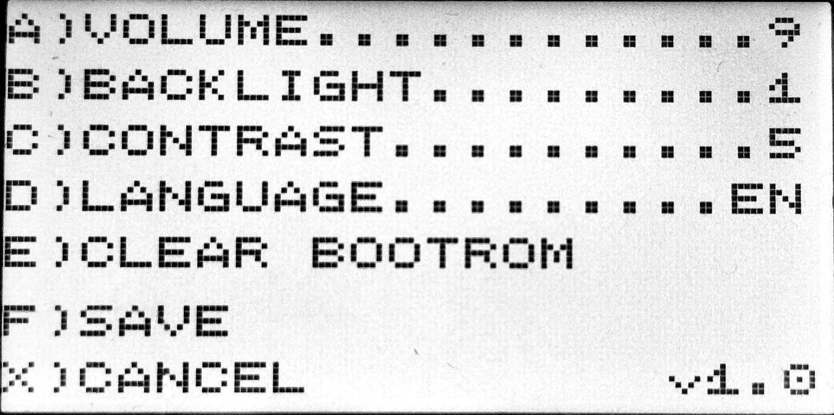
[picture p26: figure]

A | Buzzer volume. 0 is mute. Range: 0~9. Default: 9
B | LCD backlight adjustment. 0 is off. Range: 0~9. Default: 1
C | LCD contrast adjustment. Might need to adjust for clear display in different operational environments (humidity, temperature, etc.) The higher the darker. The lower the lighter. Range: 0~9. Default: 5
D | Language selection. Options: English, Toki Pona, Sitelen Pona, Sadalian Default: English
E | Clears BOOTROM. Upon power on, you'd enter the menu without going thru a BOOTROM
F | Apply changes
X | Discard changes and revert to the previous config. Does not work on BOOTROM

Firmware Update

You can perform firmware update with following the instruction:

https://ilomusi8.sadale.net/en/firmware-update

Adding New Games

You can add new games to your ilo musi 8 unit by putting new games into the TF card via the USB adapter with a computer.

After downloading the new CHIP-8 game, if needed, rename it to xxxxxxxx.CH8 and put it into your TF card. Use "8.3 filename" (uppercase with up to 8 characters with limited symbol support).

After selecting the game on your ilo musi 8 unit,

press [C] to perform "Game Config".

Select the correct config, save it and you can run the game.

As an alternative, you can use your computer to create xxxxxxxx.INI that matches your game path by following the INI specs here: https://github.com/SadaleNet/ilo-musi-8/firmware/README.MD

Some config are only accessible via direct INI modification.

You can download more CHIP-8 games here:

https://ilomusi8.sadale.net/en/roms

Other CHIP-8 games are also available elsewhere on the internet.

********************

| Developed by Sadale

https://sadale.net/

v1.0b

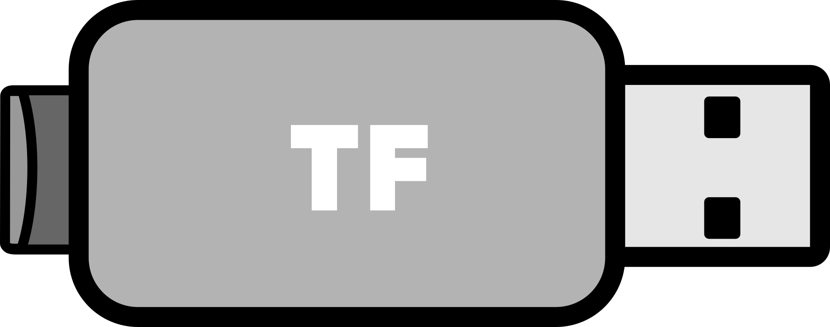
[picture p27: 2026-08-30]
manual/assets/ilo_ante.png

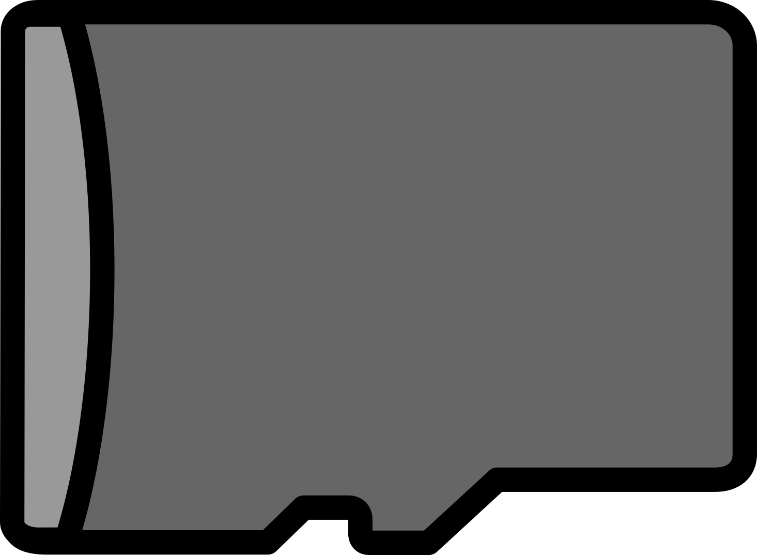
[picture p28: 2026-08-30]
manual/assets/lipu_sona_tf.png

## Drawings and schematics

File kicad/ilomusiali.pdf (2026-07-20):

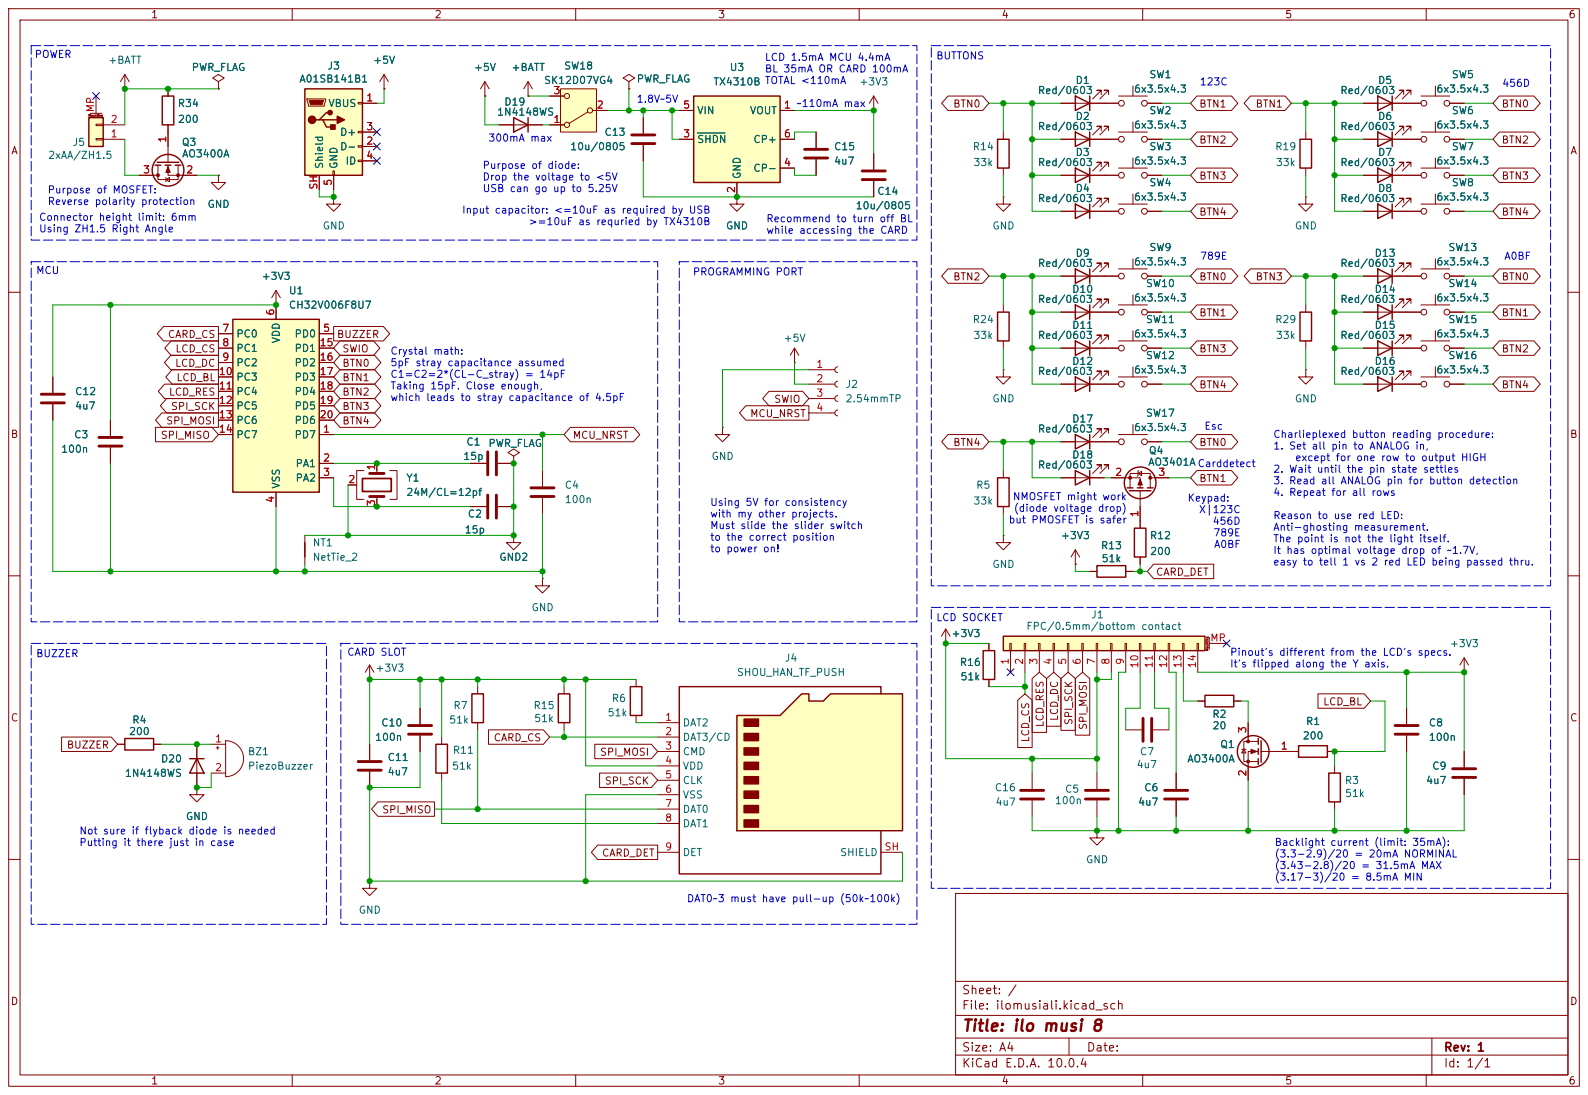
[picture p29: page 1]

TOTAL <110mA PROGRAMMING PORT Crystal math: 5pF stray capacitance assumed C1=C2=2*(CL-C_stray) = 14pF

LCD 1.5mA MCU 4.4mA BL 35mA OR CARD 100mA
~110mA max Using 5V for consistency with my other projects. Must slide the slider switch

(diode voltage drop) but PMOSFET is safer BUTTONS
6x3.5x4.3 D5 Red/0603 D6 Red/0603 D7 Red/0603 D16 Red/0603

to power on! 1.8V~5V MCU

6x3.5x4.3 D14 Red/0603 D13 Red/0603 D15 Red/0603 D8 Red/0603

Input capacitor: <=10uF as required by USB >=10uF as requried by TX4310B

Recommend to turn off BL while accessing the CARD

A0BF Not sure if flyback diode is needed Putting it there just in case
51k +3V3 D18 Red/0603 D17 Red/0603 +3V3 C3

Taking 15pF. Close enough, which leads to stray capacitance of 4.5pF

Charlieplexed button reading procedure: 1. Set all pin to ANALOG in,

except for one row to output HIGH
2. Wait until the pin state settles 3. Read all ANALOG pin for button detection 4. Repeat for all rows Reason to use red LED: Anti-ghosting measurement. The point is not the light itself.

to the correct position

Pinout's different from the LCD's specs.

Backlight current (limit: 35mA): (3.3-2.9)/20 = 20mA NORMINAL

Size: A4 | Rev: 1
KiCad E.D.A. 10.0.4 | Id: 1/1

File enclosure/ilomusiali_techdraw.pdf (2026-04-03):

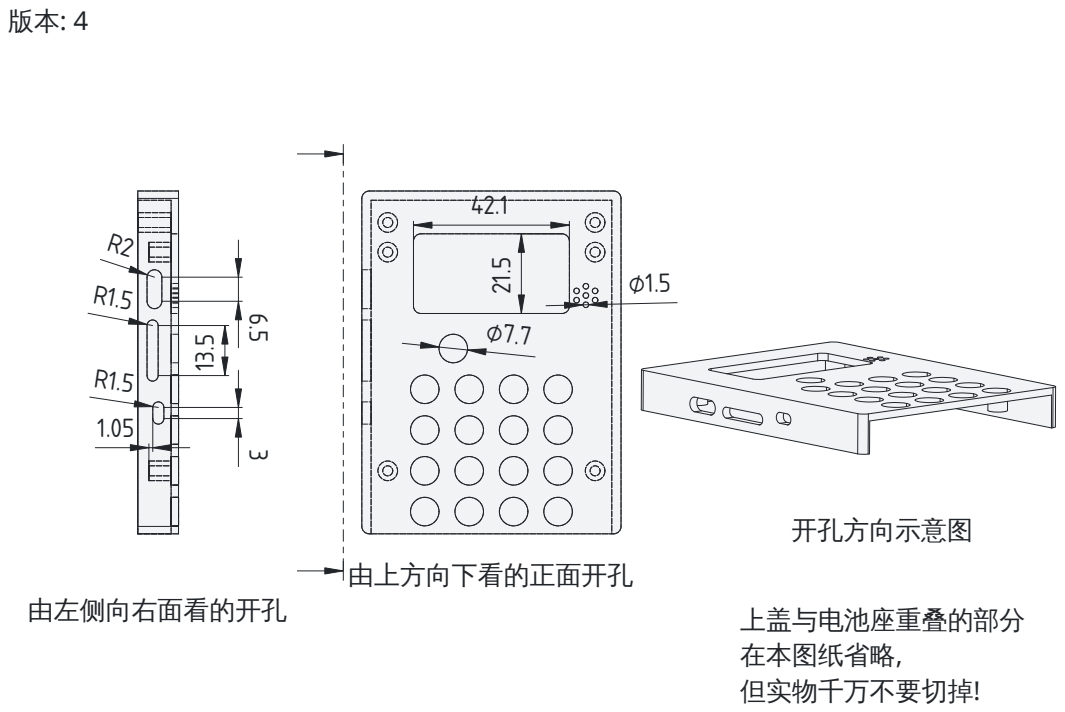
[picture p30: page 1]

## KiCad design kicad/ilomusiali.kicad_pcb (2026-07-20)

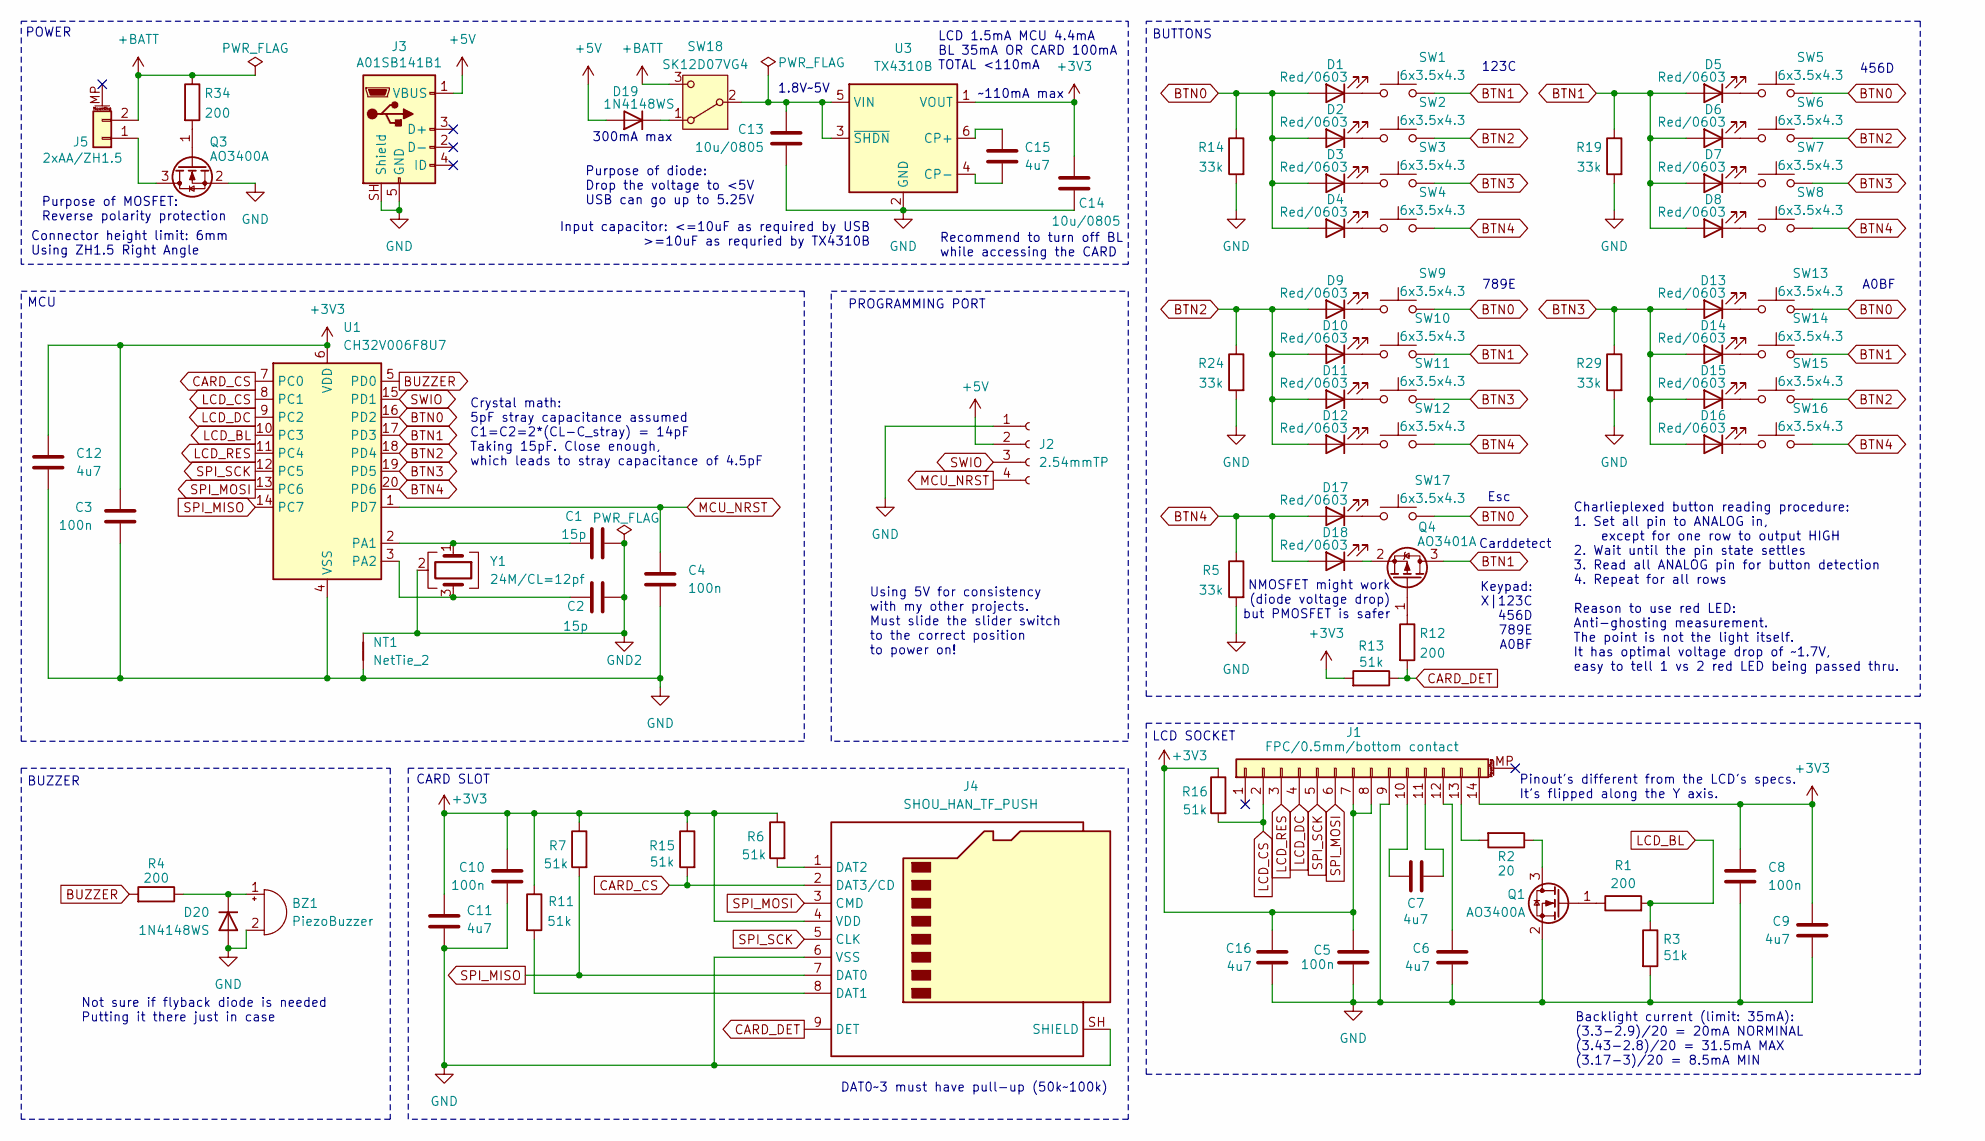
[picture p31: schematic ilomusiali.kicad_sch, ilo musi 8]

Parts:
BZ1: PiezoBuzzer; SolderWire-0.1sqmm_1x02_P3.6mm_D0.4mm_OD1mm_Relief
C1, C2: 15p; C_0603_1608Metric; LCSC C1644
C3, C4, C5, C8, C10: 100n; C_0603_1608Metric; LCSC C14663
C6, C7, C9, C11, C12, C15, C16: 4u7; C_0603_1608Metric; LCSC C19666
C13, C14: 10u/0805; C_0805_2012Metric; LCSC C15850
D1, D2, D3, D4, D5, D6, D7, D8, D9, D10, D11, D12, D13, D14, D15, D16, D17, D18: Red/0603; LED_0603_1608Metric; LCSC C2286
D19, D20: 1N4148WS; D_SOD-323; LCSC C2128
J1: FPC/0.5mm/bottom contact; Jushuo_AFC01-S14FCx-00_14P_P0.50mm_Horizontal; LCSC C577443
J2: 2.54mmTP; PinHeader_1x04_P2.54mm_Vertical
J3: A01SB141B1; USB_Micro-B_A01SB141B1-067; LCSC C404969
J4: SHOU_HAN_TF_PUSH; LCSC C393941
J5: 2xAA/ZH1.5; JST_ZH_S2B-ZR-SM4A-TF_1x02-1MP_P1.50mm_Horizontal; LCSC C2681533
NT1: NetTie_2; NetTie-2_SMD_Pad0.2mm
Q1, Q3: AO3400A; SOT-23; LCSC C20917
Q4: AO3401A; SOT-23; LCSC C15127
R1, R4, R12, R34: 200; R_0603_1608Metric; LCSC C8218
R2: 20; R_0603_1608Metric; LCSC C22950
R3, R6, R7, R11, R13, R15, R16: 51k; R_0603_1608Metric; LCSC C23196
R5, R14, R19, R24, R29: 33k; R_0603_1608Metric; LCSC C4216
SW1, SW2, SW3, SW4, SW5, SW6, SW7, SW8, SW9, SW10, SW11, SW12, SW13, SW14, SW15, SW16, SW17: 6x3.5x4.3; ZX-QC36-4.3TPWD; LCSC C7470221
SW18: SK12D07VG4; SW_Slide_SPDT_Angled_CK_OS102011MA1Q; LCSC C393937
U1: CH32V006F8U7; QFN-20-1EP_3x3mm_P0.4mm_EP1.65x1.65mm; LCSC C55112440
U3: TX4310B; SOT-23-6; LCSC C448640
Y1: 24M/CL=12pf; Crystal_SMD_3225-4Pin_3.2x2.5mm; LCSC C362340

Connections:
+3V3: C3.1, C5.1, C8.1, C9.1, C10.1, C11.1, C12.1, C14.1, C16.2, J1.7, J1.8, J1.14, J4.4 (VDD), R6.1, R7.1, R11.1, R13.2, R15.1, R16.1, U1.6 (VDD), U3.1 (VOUT)
+5V: D19.2 (A), J2.2, J3.1 (VBUS)
+BATT: J5.2, R34.1, SW18.3 (C)
BTN0: D1.2 (A), D2.2 (A), D3.2 (A), D4.2 (A), R14.1, SW5.2, SW9.2, SW13.2, SW17.2, U1.16 (PD2)
BTN1: D5.2 (A), D6.2 (A), D7.2 (A), D8.2 (A), Q4.3 (D), R19.1, SW1.2, SW10.2, SW14.2, U1.17 (PD3)
BTN2: D9.2 (A), D10.2 (A), D11.2 (A), D12.2 (A), R24.1, SW2.2, SW6.2, SW15.2, U1.18 (PD4)
BTN3: D13.2 (A), D14.2 (A), D15.2 (A), D16.2 (A), R29.1, SW3.2, SW7.2, SW11.2, U1.19 (PD5)
BTN4: D17.2 (A), D18.2 (A), R5.1, SW4.2, SW8.2, SW12.2, SW16.2, U1.20 (PD6)
BUZZER: R4.2, U1.5 (PD0)
CARD_CS: J4.2 (DAT3/CD), R15.2, U1.7 (PC0)
CARD_DET: J4.9 (DET), R12.2, R13.1
GND: BZ1.2 (-), C3.2, C4.2, C5.2, C6.2, C8.2, C9.2, C10.2, C11.2, C12.2, C13.2, C14.2, C16.1, D20.2 (A), J1.9, J2.1, J3.5 (GND), J3.SH (Shield), J4.6 (VSS), J4.SH (SHIELD), NT1.1, Q1.2 (S), Q3.2 (S), R3.2, R5.2, R14.2, R19.2, R24.2, R29.2, U1.4 (VSS), U1.21 (VSS), U3.2 (GND)
GND2: C1.1, C2.2, NT1.2, Y1.2 (G), Y1.4 (G)
LCD_BL: R1.2, R3.1, U1.10 (PC3)
LCD_CS: J1.2, R16.2, U1.8 (PC1)
LCD_DC: J1.4, U1.9 (PC2)
LCD_RES: J1.3, U1.11 (PC4)
MCU_NRST: C4.1, J2.4, U1.1 (PD7)
unnamed: BZ1.1 (+), D20.1 (K), R4.1
unnamed: D1.1 (K), SW1.1
unnamed: D2.1 (K), SW2.1
unnamed: D3.1 (K), SW3.1
unnamed: D4.1 (K), SW4.1
unnamed: D5.1 (K), SW5.1
unnamed: D6.1 (K), SW6.1
unnamed: D7.1 (K), SW7.1
unnamed: D8.1 (K), SW8.1
unnamed: D9.1 (K), SW9.1
unnamed: D10.1 (K), SW10.1
unnamed: D11.1 (K), SW11.1
unnamed: D12.1 (K), SW12.1
unnamed: D13.1 (K), SW13.1
unnamed: D14.1 (K), SW14.1
unnamed: D15.1 (K), SW15.1
unnamed: D16.1 (K), SW16.1
unnamed: D17.1 (K), SW17.1
unnamed: D18.1 (K), Q4.2 (S)
unnamed: D19.1 (K), SW18.1 (A)
unnamed: C7.1, J1.10
unnamed: C7.2, J1.11
unnamed: C6.1, J1.12
unnamed: J1.13, R2.2
unnamed: J4.8 (DAT1), R11.2
unnamed: J4.1 (DAT2), R6.2
unnamed: J5.1, Q3.3 (D)
unnamed: Q1.3 (D), R2.1
unnamed: Q1.1 (G), R1.1
unnamed: Q3.1 (G), R34.2
unnamed: Q4.1 (G), R12.1
unnamed: C13.1, SW18.2 (B), U3.3 (~SHDN), U3.5 (VIN)
unnamed: C1.2, U1.2 (PA1), Y1.1
unnamed: C2.1, U1.3 (PA2), Y1.3
unnamed: C15.1, U3.6 (CP+)
unnamed: C15.2, U3.4 (CP-)
SPI_MISO: J4.7 (DAT0), R7.2, U1.14 (PC7)
SPI_MOSI: J1.6, J4.3 (CMD), U1.13 (PC6)
SPI_SCK: J1.5, J4.5 (CLK), U1.12 (PC5)
SWIO: J2.3, U1.15 (PD1)

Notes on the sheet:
PROGRAMMING PORT
MCU
Charlieplexed button reading procedure: 1. Set all pin to ANALOG in, except for one row to output HIGH 2. Wait until the pin state settles 3. Read all ANALOG pin for button detection 4. Repeat for all rows Reason to use red LED: Anti-ghosting measurement. The point is not the light itself. It has o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
Connector height limit: 6mm Using ZH1.5 Right Angle
Keypad: X|123C 456D 789E A0BF
456D
NMOSFET might work (diode voltage drop) but PMOSFET is safer
Not sure if flyback diode is needed Putting it there just in case
Pinout's different from the LCD's specs. It's flipped along the Y axis.
Recommend to turn off BL while accessing the CARD
789E
Backlight current (limit: 35mA): (3.3-2.9)/20 = 20mA NORMINAL (3.43-2.8)/20 = 31.5mA MAX (3.17-3)/20 = 8.5mA MIN
LCD SOCKET
Crystal math: 5pF stray capacitance assumed C1=C2=2*(CL-C_stray) = 14pF Taking 15pF. Close enough, which leads to stray capacitance of 4.5pF
Using 5V for consistency with my other projects. Must slide the slider switch to the correct position to power on!
CARD SLOT
Purpose of diode: Drop the voltage to <5V USB can go up to 5.25V
Carddetect
Purpose of MOSFET: Reverse polarity protection
LCD 1.5mA MCU 4.4mA BL 35mA OR CARD 100mA TOTAL <110mA
1.8V~5V
Input capacitor: <=10uF as required by USB >=10uF as requried by TX4310B
300mA max
Esc
123C
BUTTONS
POWER
~110mA max
BUZZER
A0BF
DAT0~3 must have pull-up (50k~100k)

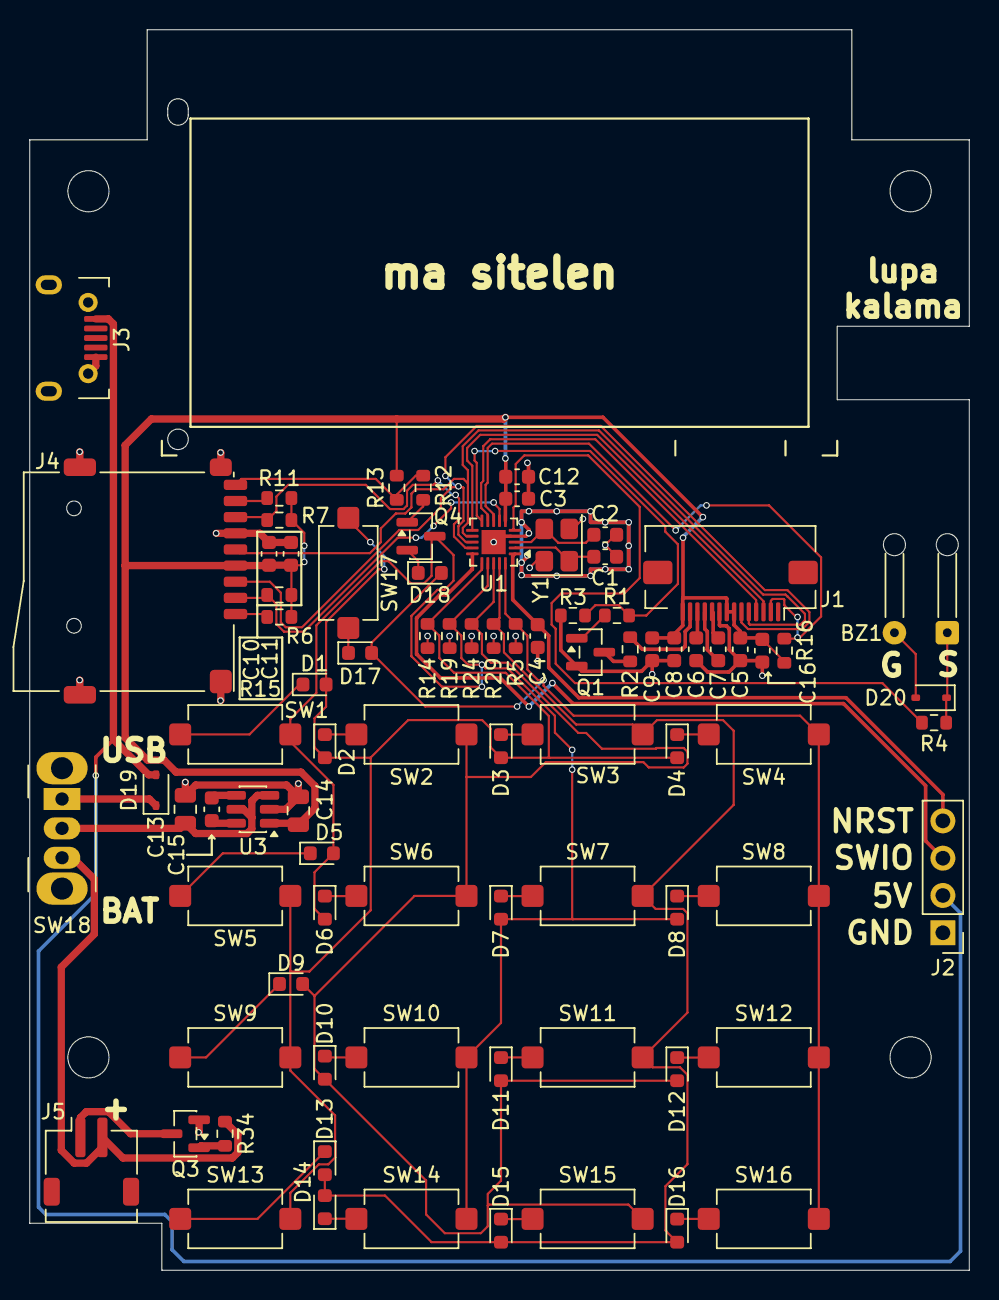
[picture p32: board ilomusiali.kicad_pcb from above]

Board: 2 copper layers, 64.0 x 84.5 mm, 84 parts (0 on the bottom side), 58 nets.

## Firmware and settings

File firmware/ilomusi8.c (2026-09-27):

// Copyright 2026 Wong Cho Ching <https://sadale.net>
//
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
// 1. Redistributions of source code must retain the above copyright
// notice, this list of conditions and the following disclaimer.
//
// 2. Redistributions in binary form must reproduce the above copyright
// notice, this list of conditions and the following disclaimer in the
// documentation and/or other materials provided with the distribution.
//
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
#include "chip8.h"
#include "bulkmem.h"

#include "adc.h"
#include "bootrom.h"
#include "buzzer.h"
#include "config.h"
#include "draw.h"
#include "file.h"
#include "flash.h"
#include "generated.h"
#include "lcd.h"
#include "spi.h"
#include "tim1_pwm.h"
#include "watchdog.h"
#include "util.h"

#include "fatfs/ff.h"
#include "ch32fun.h"
#include <stdio.h>
#include <string.h>
#include <assert.h>

#define FIRMWARE_VERSION "v1.0"
#define HW_TEST_MODE_BUTTONS ((1<<0xD)|(1<<0xE)) // Hold button D and E to enter SCREEN_HW_TEST
#define GAMEPLAY_INSTRUCTION_DURATION_MS (5000U) // Show gameplay instruction for this long
#define GAMEPLAY_EXIT_DURATION_MS (3000U) // Tell the user to hold <X> for this long to exit the game
#define GAMEPLAY_EXIT_BANNER_ROW_POS (3) // The row position of the EXIT banner for warning the user about the exit
#define GAMEPLAY_EXIT_BANNER_ROW_HEIGHT (2) // How tall the confirm game quit banner is. Each row is 8px.

// State Transition Table for screen_state
// FROM \ TO		ERROR			MENU			GAME_CONFIG		GLOBAL_CONFIG	PRE_GAMEPLAY	GAMEPLAY		GAMEOVER		GAME_CRASHED	FW_UPDATE_OK	HW_TEST
// INIT				ilomusi8.binERR																	BOOTROM exists									ilomusi8.binOK	D&E_HELD
// ERROR			*				X_pressed						D_pressed
// MENU				CARD_ERR		*				C_pressed		D_pressed		F_pressedw/info	F_pressednoinfo
// GAME_CONFIG		CARD_ERR		X_pressed		*
// GLOBAL_CONFIG					X_pressed						*
// PRE_GAMEPLAY						X_pressed										*				any_pressed/wait
// GAMEPLAY			saveflag_ERR	X_held^1														*				exit_detected^2	crash_detected
// GAMEOVER							X_pressed																		*
// GAME_CRASHED						X_pressed																						*
// FW_UPDATE_OK						X_pressed																										*
// HW_TEST																																							*
// ^1 For BOOTROM, X_pressed instead of X_held would trigger GAMEPLAY->MENU transition; X_held means that the user would need to hold X for a few seconds to quit
// ^2 For BOOTROM, upon the game exits, it'd switch to MENU instead of GAMEOVER

enum screen_state {
	SCREEN_ERROR, // File IO Error Screen
	SCREEN_MENU,
	SCREEN_GAME_CONFIG, // game-specific configuration. Saved into an INI file
	SCREEN_GLOBAL_CONFIG, // configuration applied to the entire game console. Saved into internal flash.
	SCREEN_PRE_GAMEPLAY, // show controls and possibly keyboard layout remap
	SCREEN_GAMEPLAY,
	SCREEN_GAMEOVER,
	SCREEN_GAME_CRASHED,
	SCREEN_FW_UPDATE_OK,
	SCREEN_HW_TEST,
};

enum game_config_selection {
	GAME_CONFIG_MAIN,
	GAME_CONFIG_QUIRKS,
	GAME_CONFIG_QUIRKS_CUSTOM,
	GAME_CONFIG_SPEED,
	GAME_CONFIG_BOOT_ROM,
};

enum global_config_selection {
	GLOBAL_CONFIG_MAIN,
	GLOBAL_CONFIG_VOLUME,
	GLOBAL_CONFIG_BACKLIGHT,
	GLOBAL_CONFIG_CONTRAST,
	GLOBAL_CONFIG_LANGUAGE,
	GLOBAL_CONFIG_BOOT_ROM,
};

static uint32_t chip8_keymap(uint32_t button_state) {
	// Converts from the left layout to the right layout
	//      [16]                      [0x10]
	// [0]  [1]  [2]  [3]         [1] [2] [3] [C]
	// [4]  [5]  [6]  [7]         [4] [5] [6] [D]
	// [8]  [9]  [10] [11]        [7] [8] [9] [E]
	// [12] [13] [14] [15]        [A] [0] [B] [F]
	uint32_t ret = 0;
	const unsigned int BUTTON_MAP[] = {13, 0, 1, 2, 4, 5, 6, 8, 9, 10,
										12, 14, 3, 7, 11, 15, 16};
	for(int i=0; i<sizeof(BUTTON_MAP)/sizeof(*BUTTON_MAP); i++) {
		if(button_state & (1<<BUTTON_MAP[i])) {
			ret |= 1<<i;
		}
	}
	return ret;
}

static void directory_attach_filename(char *directory_str, const char *filename) {
	// Warning: No boundary check in this function
	// The boundary check's handled upon entering the direcotry (strlen(menu_current_dir) >= sizeof(menu_current_dir)-13-1)
	size_t current_dir_length = strlen(directory_str);
	memcpy(&directory_str[current_dir_length], filename, strlen(filename)+1);
}

static void directory_remove_filename(char *directory_str) {
	char *result = strrchr(directory_str, '/');
	if(result != NULL) {
		result[1] = '\0'; // Remove filename. Keep trailing slash.
	} else {
		directory_str[0] = '\0';
	}
}

static void directory_up(char *directory_str, char exited_directory_str[14]) {
	if(strlen(directory_str) >= 1) {
		// Remove the trailing slash
		directory_str[strlen(directory_str)-1] = '\0';

		// Find the next trailing slash
		char *result = strrchr(directory_str, '/');
		char *removed_directory_ptr = NULL;
		if(result != NULL) {
			removed_directory_ptr = &result[1]; // That's the directory name after the trailing slash
		} else {
			removed_directory_ptr = directory_str; // No trailing slash found. The entire content's filename.
		}

		// Extract the directory that we just exited and fill it into exited_directory_str
		if(exited_directory_str != NULL) {
			strncpy(exited_directory_str, removed_directory_ptr, 13);
			exited_directory_str[13-1] = '\0';
			// Add back the previously removed trailing slash
			int length = strlen(exited_directory_str); // max length 12
			exited_directory_str[length] = '/';
			exited_directory_str[length+1] = '\0';
		}

		// Remove the directory we're exiting from to go up
		*removed_directory_ptr = '\0';
	}
}

// Shared buffer definition for saving RAM space
union {
	struct chip8_config chip8_cfg; // Used in all screens except for SCREEN_GAMEPLAY
	uint8_t game_paused_screen_buffer_backup[GAMEPLAY_EXIT_BANNER_ROW_HEIGHT][DISPLAY_WIDTH]; // Used in SCREEN_GAMEPLAY
} union_buffer;

// Shared by all screens
struct shared_buffer *bulkmem;
static struct chip8_machine chip8;
struct chip8_config *chip8_cfg;
enum screen_state screen_state;
struct global_config global_config;
struct global_config global_config_backup;
uint32_t systick_now;

// Shared by all screens except for SCREEN_GAMEPLAY
bool menu_display_update_required;

// For SCREEN_MENU
char (*menu_file_list)[14];
char menu_current_dir[256]; // Must not use bulkmem because this path's used for loading the ROM
char menu_prev_dir[14]; // Used for selecting the directory in the parent directory when we do up-dir
bool menu_cache_invalidated; // Must invalidate upon bulkmem's filled by game ROM, upon path change, or upon change of directory's content
int menu_offset;
uint8_t file_io_result;
size_t menu_file_count_of_current_page;

// Shortcut definitions for SCREEN_MENU and SCREEN_GAME_CONFIG
#define MENU_OFFSET_ON_CURRENT_PAGE (menu_offset%MENU_PAGE_SIZE)
#define MENU_SELECTED_FILENAME (menu_file_list[MENU_OFFSET_ON_CURRENT_PAGE])

// For SCREEN_GAME_CONFIG
enum game_config_selection game_config_selection;
uint8_t game_config_index;
uint32_t game_config_old_value;

// For SCREEN_GLOBAL_CONFIG
enum global_config_selection global_config_selection;
uint32_t global_config_old_value;
uint32_t global_config_buzzer_start_tick;

// For SCREEN_GAMEPLAY
uint8_t last_storage_flag[sizeof(chip8_cfg->storage_flags)/sizeof(*chip8_cfg->storage_flags)]; // storage flag state upon game launch
uint32_t game_min_cycle_interval;
uint32_t last_frame_processed_tick;
uint32_t last_lcd_blit_tick;
uint8_t game_paused;
bool game_is_bootrom;
uint32_t game_paused_start_tick; // After pausing for long enough (i.e. holding X for long enough), the game would be quit.
uint8_t (*game_paused_screen_buffer_backup)[DISPLAY_WIDTH]; // The pause message overlays on the game's display. Need to restore upon unpause.

// For SCREEN_HW_TEST
uint32_t hw_test_audio_cycle_start_tick;
uint32_t hw_test_last_refresh_tick;
uint32_t hw_test_last_voltage_update_tick;
bool hw_test_backlight_toggled;
bool hw_test_button_test_mode;
uint8_t hw_test_button_test_counter[17];
uint32_t hw_test_voltage_reading;


static void wait_button_release(void) {
	// Clean screen reasons:
	// 1. We wait until release of all buttons.
	// In case a button got held, the old screen content would get shown.
	// 2. For SCREEN_PRE_GAMEPLAY, we stole the display buffer for showing the controls
	// so we also must clean it up before running the CHIP-8 emulator
	draw_clear(chip8.periph.display);
	lcd_transfer_begin(chip8.periph.display);
	// Wait until all buttons got released
	// That's because CHIP-8 has a instruction that waits for key release
	// If the button got pressed while the game's launched,
	// the button release would be detected by the game
	while(chip8_keymap(adc_button_get_state()));
	// Get rid of all button press events
	adc_button_get_just_pressed();
	adc_button_get_just_released();
}

static void apply_volume(bool with_sound) {
	assert(global_config.volume < GLOBAL_CONFIG_MAX_VALUE);
	static const uint8_t VOLUME_MAP[GLOBAL_CONFIG_MAX_VALUE] = {0, 1, 2, 4, 6, 8, 10, 12, 14, 15};
	buzzer_set_volume(with_sound ? VOLUME_MAP[global_config.volume] : 0);
}

static void apply_volume_with_feedback_sound(void) {
	buzzer_set_pitch(CHIP8_DEFAULT_AUDIO_PITCH);
	buzzer_set_buffer(CHIP8_DEFAULT_AUDIO_SAMPLE);
	apply_volume(true);
	global_config_buzzer_start_tick = systick_now;
}

static void apply_brightness(void) {
	assert(global_config.backlight < GLOBAL_CONFIG_MAX_VALUE);
	static const uint8_t BRIGHTNESS_MAP[GLOBAL_CONFIG_MAX_VALUE] = {0, 1, 2, 3, 5, 6, 7, 9, 11, 15};
	lcd_set_brightness(BRIGHTNESS_MAP[global_config.backlight]);
}

static void apply_contrast(void) {
	assert(global_config.contrast < GLOBAL_CONFIG_MAX_VALUE);
	static const uint8_t CONTRAST_MAP[GLOBAL_CONFIG_MAX_VALUE] = {0x18, 0x1A, 0x1C, 0x1E, 0x20, 0x22, 0x24, 0x26, 0x28, 0x2A};
	lcd_set_contrast(CONTRAST_MAP[global_config.contrast]);
}

static void draw_message_with_dots_suffix(enum tr_msg_id msg_id, uint8_t max_dots, uint8_t x, uint8_t y) {
	draw_translated(chip8.periph.display, global_config.language, msg_id, x, y);
	uint8_t width = draw_get_translated_width(global_config.language, msg_id);
	char str[22];
	uint8_t prefix_letters = (width+5)/6;
	memset(str, '.', max_dots-prefix_letters);
	str[max_dots-prefix_letters] = '\0';
	draw_text(chip8.periph.display, str, 12+prefix_letters*6, y+Y_ADJ);
}

static void prepare_game_launch(void) {
	memcpy(last_storage_flag, chip8_cfg->storage_flags, sizeof(chip8_cfg->storage_flags));
	// Initialize peripheral variables
	buzzer_set_buffer(chip8.periph.audio);
	buzzer_set_pitch(chip8.periph.audio_pitch);
	if(chip8_cfg->speed == 0) {
		game_min_cycle_interval = 0; // Unlimited framerate
	} else {
		game_min_cycle_interval = FUNCONF_SYSTEM_CORE_CLOCK/60/chip8_cfg->speed;
	}
	last_frame_processed_tick = systick_now - game_min_cycle_interval;
	last_lcd_blit_tick = systick_now - FUNCONF_SYSTEM_CORE_CLOCK/60;
	game_paused = false;
}

static void screen_error_handler(void) {
	bool device_disabled = (file_io_result == FR_LOW_BATTERY);
	if(!device_disabled) {
		uint32_t button_press = chip8_keymap(adc_button_get_just_pressed());
		if(button_press & (1<<0x10)) {
			screen_state = SCREEN_MENU;
		} else if((button_press & (1<<0xD))) { // Allows visiting global config screen with D button even with card error
			memcpy(&global_config_backup, &global_config, sizeof(global_config_backup));
			menu_display_update_required = true;
			screen_state = SCREEN_GLOBAL_CONFIG;
		}

		if(screen_state != SCREEN_ERROR) {
			// Always invalidate cache and change to root directory
			// and reset cursor before leaving the screen.
			// This way next time we land on SCREEN_MENU, via or not via SCREEN_GLOBAL_CONFIG,
			// we'd always retry loading the root directory
			menu_current_dir[0] = '\0';
			menu_prev_dir[0] = '\0';
			menu_offset = 0;
			menu_cache_invalidated = true;
			return;
		}
	}

	if(menu_display_update_required) {
		draw_clear(chip8.periph.display);
		draw_text(chip8.periph.display, "XXXXXXXXXXXXXXXXXXXXX", 0, 0);
		draw_translated(chip8.periph.display, global_config.language, TR_MSG_ERR_TITLE, 0, 10);

		char errorcode[3] = {0};
		errorcode[0] = file_io_result/10 + '0';
		errorcode[1] = file_io_result%10 + '0';
		errorcode[2] = '\0';
		draw_text(chip8.periph.display, errorcode, draw_get_translated_width(global_config.language, TR_MSG_ERR_TITLE), 10+Y_ADJ);
		switch(file_io_result) {
			case FR_NOT_READY: // No card
				draw_translated(chip8.periph.display, global_config.language, TR_MSG_ERR_NOT_READY, 0, 20);
			break;
			case FR_NO_FILESYSTEM:
				draw_translated(chip8.periph.display, global_config.language, TR_MSG_ERR_NO_FILESYSTEM, 0, 20);
				draw_translated(chip8.periph.display, global_config.language, TR_MSG_ERR_NO_FILESYSTEM2, 0, 30);
			break;
			case FR_INI_PARSE_ERROR:
				draw_translated(chip8.periph.display, global_config.language, TR_MSG_ERR_INI_PARSE, 0, 20);
			break;
			case FR_VOLUME_FULL:
				draw_translated(chip8.periph.display, global_config.language, TR_MSG_ERR_VOLUME_FULL, 0, 20);
			break;
			case FR_PATH_LENGTH_ERROR:
				draw_translated(chip8.periph.display, global_config.language, TR_MSG_ERR_PATH_LENGTH, 0, 20);
			break;
			case FR_FIRMWARE_VERIFICATION_ERROR:
				draw_translated(chip8.periph.display, global_config.language, TR_MSG_ERR_FIRMWARE_VERIFICATION, 0, 20);
			break;
			case FR_BOOTROM_VERIFICATION_ERROR:
				draw_translated(chip8.periph.display, global_config.language, TR_MSG_ERR_BOOTROM_VERIFICATION, 0, 20);
			break;
			case FR_LOW_BATTERY:
				draw_translated(chip8.periph.display, global_config.language, TR_MSG_ERR_LOW_BATTERY, 0, 20);
			break;
			default:
			break;
		}
		if(!device_disabled) {
			draw_translated(chip8.periph.display, global_config.language, TR_MSG_ERR_PROCEED, 0, 48);
		}
		draw_text(chip8.periph.display, "XXXXXXXXXXXXXXXXXXXXX", 0, 58);
		lcd_transfer_begin(chip8.periph.display);
		menu_display_update_required = false;
	}
}

static bool screen_menu_selected_item_is_a_file(void) {
	return (!menu_cache_invalidated && // content of menu_file_list is valid
			menu_file_count_of_current_page > 0 && // non-empty directory
			strlen(MENU_SELECTED_FILENAME) > 0 && // Boundary check for the next condition
			MENU_SELECTED_FILENAME[strlen(MENU_SELECTED_FILENAME)-1] != '/' // Not having trailing slash
		);
}
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
int main() {
	// Kickoff the watchdog as early as possible
	watchdog_init();

	SystemInit();

	// Enables interrupt preempt feature
	__set_INTSYSCR( __get_INTSYSCR() | 0x02 );

	adc_init();
	tim1_pwm_init(); // Required by LCD and buzzer
	buzzer_init();

	lcd_init_first_stage(); // Initialize IO. Turns off LCD
	spi_init(); // Depends on lcd_init_first_stage()

	while(!adc_is_reading_ready()){} // Depends on tim1_pwm_init()

	// Depends on adc_is_reading_ready()
	file_first_mount();

	spi_set_mode(SPI_MODE_LCD);
	lcd_init_second_stage(); // If card's inserted, must be done after spi_card_mount_filesystem()

	config_load(&global_config);
	apply_volume(false); // Always use mute the buzzer at the beginning
	apply_brightness();
	apply_contrast();

	watchdog_feed();

	static_assert(sizeof(struct shared_buffer) <= sizeof(chip8.mem));
	bulkmem = (struct shared_buffer*)chip8.mem;
	chip8_cfg = &union_buffer.chip8_cfg;
	game_paused_screen_buffer_backup = union_buffer.game_paused_screen_buffer_backup;

	// Shared by all screens except for SCREEN_GAMEPLAY
	menu_display_update_required = true;

	// For SCREEN_MENU
	menu_file_list = bulkmem->menu_file_list;
	menu_current_dir[0] = '\0';
	menu_prev_dir[0] = '\0';
	menu_offset = 0;
	menu_file_count_of_current_page = 0;
	menu_cache_invalidated = true;
	file_io_result = FR_OK;

	// For SCREEN_GAME_CONFIG
	game_config_selection = GAME_CONFIG_MAIN;
	game_config_index = 0;
	game_config_old_value = 0;

	// For SCREEN_GAMEPLAY
	game_min_cycle_interval = 0;
	last_frame_processed_tick = SysTick->CNT;
	last_lcd_blit_tick = SysTick->CNT;
	game_is_bootrom = false;

	if((chip8_keymap(adc_button_get_state()) & HW_TEST_MODE_BUTTONS) == HW_TEST_MODE_BUTTONS) {
		// For SCREEN_HW_TEST: Firmware test button combination detected. Entering firmware test mode!
		buzzer_set_buffer(CHIP8_DEFAULT_AUDIO_SAMPLE);
		hw_test_audio_cycle_start_tick = SysTick->CNT + UINT32_MAX/2;
		hw_test_backlight_toggled = true;
		hw_test_button_test_mode = false;
		memset(chip8.periph.display, 0xFF, sizeof(chip8.periph.display)); // Set all LCD pixels to black
		memset(hw_test_button_test_counter, 0, sizeof(hw_test_button_test_counter));
		hw_test_voltage_reading = 0;
		hw_test_last_refresh_tick = systick_now;
		screen_state = SCREEN_HW_TEST;
	} else {
		// Verify firmware update content
		file_io_result = file_verify_firmware_update();

		switch(file_io_result) {
			case FR_OK:
				screen_state = SCREEN_FW_UPDATE_OK;
			break;
			case FR_FIRMWARE_VERIFICATION_ERROR:
				screen_state = SCREEN_ERROR;
			break;
			case FR_NO_FILE: // Firmware update file not found, which's a perfectly normal case. Gotta suppress this error
				file_io_result = FR_OK;
			default: // Fallthrough. (default is "other error occurred")
				// For the case of "other error had occurred", there's no need to jump to SCREEN_ERROR for now
				// After the bootrom exits, the error would be shown
				// There's a slight chance that the file_io_result would be overwritten but that's ok
				// because we're already having io error. Chances are that it'd just be replaced by another error
				if(bootrom_load(chip8_cfg, &chip8)) {
					prepare_game_launch();
					game_is_bootrom = true;
					screen_state = SCREEN_GAMEPLAY;
				} else {
					screen_state = SCREEN_MENU;
				}
			break;
		}
	}

	while(true) {
		file_loop();

		systick_now = SysTick->CNT;
		enum screen_state screen_state_prev = screen_state;
		switch(screen_state) {
			case SCREEN_ERROR: screen_error_handler(); break;
			case SCREEN_MENU: screen_menu_handler(); break;
			case SCREEN_GAME_CONFIG: screen_game_config_handler(); break;
			case SCREEN_GLOBAL_CONFIG: screen_global_config_handler(); break;
			case SCREEN_PRE_GAMEPLAY: screen_pre_gameplay_handler(); break;
			case SCREEN_GAMEPLAY: screen_gameplay_handler(); break;
			case SCREEN_GAMEOVER: screen_gameover_handler(); break;
			case SCREEN_GAME_CRASHED: screen_game_crashed_handler(); break;
			case SCREEN_FW_UPDATE_OK: screen_fw_update_ok_handler(); break;
			case SCREEN_HW_TEST: screen_hw_test_handler(); break;
		}

		if(screen_state != screen_state_prev) {
			// The LCD's specs recommends calling this function once a while
			// I'm gonna call it upon screen switch.
			// It also double as visual feedback to the user because
			// the screen would go blank for like 0.3s when this function's called
			lcd_refresh();
		}

		watchdog_feed();
	}
}

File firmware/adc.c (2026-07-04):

// Copyright 2026 Wong Cho Ching <https://sadale.net>
//
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
// 1. Redistributions of source code must retain the above copyright
// notice, this list of conditions and the following disclaimer.
//
// 2. Redistributions in binary form must reproduce the above copyright
// notice, this list of conditions and the following disclaimer in the
// documentation and/or other materials provided with the distribution.
//
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
#include "adc.h"
#include "ch32fun.h"
#include <stdbool.h>

struct adc_row_scan_config {
	uint8_t pin_channel;
	uint32_t adc_scan_sequence; // The value set to ADC1->RSQR3
};

// Layout of adc_dma_buffer/adc_button_state/adc_button_just_pressed/adc_button_just_released:
//      [16]
// [0]  [1]  [2]  [3]
// [4]  [5]  [6]  [7]
// [8]  [9]  [10] [11]
// [12] [13] [14] [15]
// 17: card insert
// 18 and 19: Vref internal voltage reference

// 16bit would fit but I'm using 32bit for performance
uint32_t adc_dma_buffer[20];
uint32_t adc_dma_buffer_debounce; // Record the previous data. For debouncing. Only take the input after 2 consecutive same data.
uint32_t adc_button_state; // CONCURRENCY_VARIABLE: Written in adc_button_scan_next_row(), read by adc_button_get_state()
uint32_t adc_button_just_pressed; // CONCURRENCY_VARIABLE: Written in adc_button_scan_next_row(), read and reset in adc_button_get_just_pressed()
uint32_t adc_button_just_released; // CONCURRENCY_VARIABLE: Written in adc_button_scan_next_row(), read and reset in adc_button_get_just_released()
bool adc_card_inserted; // CONCURRENCY_VARIABLE: Written in adc_button_scan_next_row(), read by adc_card_is_inserted()
bool adc_card_just_inserted; // CONCURRENCY_VARIABLE: Written in adc_button_scan_next_row(), read by adc_card_has_insert_event(), reset by adc_card_reset_insert_event()
bool adc_card_just_removed; // CONCURRENCY_VARIABLE: Written in adc_button_scan_next_row(), read and reset by adc_card_is_just_removed()
uint32_t adc_vref_reading_smoothed; // CONCURRENCY_VARIABLE: Written in adc_button_scan_next_row(), read by adc_get_supply_voltage()
bool adc_reading_ready; // CONCURRENCY_VARIABLE: Written in adc_button_scan_next_row(), read by adc_is_reading_ready()
#define ADC_BUTTON_STATE_SIZE (17)
#define ADC_BUTTON_PRESSED_THRESHOLD (1024) // Any ADC reading above this value would be considered as button pressed
#define ADC_READING_READY_THRESHOLD (10) // The ADC readings is regarded as READY after this amount of complete scans

#if ADC_BUTTON_STATE_SIZE >= 32
	#error adc_button_state, adc_button_just_pressed and adc_button_just_released are unable to accomodate the content of adc_dma_buffer
#endif

static const struct adc_row_scan_config row_scan_config[] = {
	{.pin_channel = 2, .adc_scan_sequence = (4U << (5*0)) | (7U << (5*1)) | (5U << (5*2)) | (6U << (5*3))},
	{.pin_channel = 3, .adc_scan_sequence = (3U << (5*0)) | (7U << (5*1)) | (5U << (5*2)) | (6U << (5*3))},
	{.pin_channel = 4, .adc_scan_sequence = (3U << (5*0)) | (4U << (5*1)) | (5U << (5*2)) | (6U << (5*3))},
	{.pin_channel = 5, .adc_scan_sequence = (3U << (5*0)) | (4U << (5*1)) | (7U << (5*2)) | (6U << (5*3))},
	{.pin_channel = 6, .adc_scan_sequence = (3U << (5*0)) | (4U << (5*1)) | (8U << (5*2)) | (8U << (5*3))}, // The last two channels here is set to the internal Vref
};

#define ROW_SCAN_SEQUENCE_CHANNEL_COUNT (4)
// ADC sampling time configuration. configuring 0~7 means 3.5/7.5/11.5/19.5/35.5/55.5/71.5/239.5 cycles
// At maximum value 7, ADC clk div16, it's empiracally found that a full scan would be performed at frequency of 727 Hz
#define ADC_SAMPLING_TIME (7)

void adc_button_scan_next_row(void) {
	static size_t row_scan_index = 0;
	static size_t scan_completion_counter = 0;

	// read memory barrier to make sure that the content of adc_dma_buffer is fresh
	asm volatile("fence ir,ir" ::: "memory");
	// Compiler-level barrier for adc_... variables so that the adc_... variables wouldn't have to be defined as volatile
	asm volatile("" ::: "memory");

	// Handle button press and save the states to adc_button_state, adc_button_just_pressed and adc_button_just_released
	// Not performing debounce handling because the ADC reading's slow enough
	for(size_t i=ROW_SCAN_SEQUENCE_CHANNEL_COUNT*row_scan_index; i<ROW_SCAN_SEQUENCE_CHANNEL_COUNT*(row_scan_index+1) && i<ADC_BUTTON_STATE_SIZE; i++) {
		uint32_t button_mask = (1U<<i);
		bool button_pressed = (adc_dma_buffer[i] >= ADC_BUTTON_PRESSED_THRESHOLD);
		if(button_pressed && (adc_dma_buffer_debounce & button_mask)) {
			// Button held
			if(!(adc_button_state & button_mask)) {
				adc_button_just_pressed |= button_mask;
			}
			adc_button_state |= button_mask;
		} else if (!button_pressed && !(adc_dma_buffer_debounce & button_mask)) {
			// Button not held
			if(adc_button_state & button_mask) {
				adc_button_just_released |= button_mask;
			}
			adc_button_state &= ~button_mask;
		}
		// For debouncing. Only count the button press after detecting the same value twice
		if(button_pressed) {
			adc_dma_buffer_debounce |= button_mask;
		} else {
			adc_dma_buffer_debounce &= ~button_mask;
		}
	}

	// Derive card insertion state and vref
	if(row_scan_config[row_scan_index].pin_channel == 6) {
		bool adc_card_inserted_prev = adc_card_inserted;
		adc_card_inserted = (adc_dma_buffer[17] >= ADC_BUTTON_PRESSED_THRESHOLD);
		if(!adc_card_inserted_prev && adc_card_inserted) {
			adc_card_just_inserted = true;
		} else if(adc_card_inserted_prev && !adc_card_inserted) {
			adc_card_just_removed = true;
		}
		uint32_t adc_vref_reading = (adc_dma_buffer[18]+adc_dma_buffer[19])/2;
		adc_vref_reading_smoothed = (adc_vref_reading_smoothed*7 + adc_vref_reading*1 + 4)/8; // +4 for rounding off the /8
	}

	// Determine which row to scan next
	if(++row_scan_index >= sizeof(row_scan_config)/sizeof(*row_scan_config)) {
		row_scan_index = 0;
		// Determine if the reading is ready to be retrieved
		if(scan_completion_counter <= ADC_READING_READY_THRESHOLD) {
			if(scan_completion_counter == ADC_READING_READY_THRESHOLD) {
				// Reset just pressed and just released button events so that the button held before the readings' ready
				// would be disregarded
				adc_button_just_pressed = 0;
				adc_button_just_released = 0;
				// Make adc_is_reading_ready() return true
				adc_reading_ready = true;
			}
			scan_completion_counter++;
		}
	}

	// Configure DMA for the next read
	DMA1_Channel1->CFGR &= ~DMA_CFGR1_EN; // As per the specs, must disable DMA channel before configuring it
	DMA1_Channel1->MADDR = (uint32_t)&adc_dma_buffer[ROW_SCAN_SEQUENCE_CHANNEL_COUNT*row_scan_index]; // memory destination
	DMA1_Channel1->CNTR = ROW_SCAN_SEQUENCE_CHANNEL_COUNT; // number of items to read
	DMA1_Channel1->CFGR |= DMA_CFGR1_EN; // Re-enable the DMA channel
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

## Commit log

2026-02-08 Initial commit with schematics draft
    [ilomusiali.kicad_pcb, ilomusiali.kicad_sch]
2026-02-11 electronics: Fixed a few bugs, including battery polarity protection bug, using a better diode, lowered USB serial resistor's value and fixed potential short circuit condition in case the Esc button 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
    [ilomusiali.kicad_sch]
2026-02-21 electronics: Made first draft of component placement
    [ilomusiali.kicad_pcb, ilomusiali.kicad_sch]
2026-03-11 electronics: Completed layout for PCB rev0
    [ilomusiali.kicad_pcb, ilomusiali.kicad_sch]
2026-03-11 electronics: PCB rev0: Enlarged the LCD mounting holes to account for tolerance. This is the PCB rev0 sent for manufacturing
    [ilomusiali.kicad_pcb]
2026-04-03 enclosure: First commit. This is the design I sent for first prototype manufacturing
    [ilomusiali.FCStd, ilomusiali_techdraw.dxf]
2026-04-03 enclosure: Drawing updated for clearing up ambiguity. This was never sent to the manufacturer I'm using.
    The way to manufacture this enclosure is to purchase an
    off-the-shelf enclosure and ask the manufacturer to CNC-mill it.
    The previous version of the enclosure drawing was ambigious and
    it got manufactured incorrectly. The side holes were shifted downward by 1mm.
    I communicated with the manufacturer and they agreed to shift the
    holes back upward by 1mm. They told me not to send them a new drawing.
    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
    [ilomusiali.FCStd, ilomusiali_techdraw.dxf]
2026-04-03 enclosure_label: Added key label for the enclosure
2026-05-15 firmware: Implemented all ADC features, including button driver, card prescence detection and supply voltage detection
2026-05-21 adc: Fixed card insert detection bug; Make it configure the DMA count after configuring the address; Reset ADC on initialization
    [adc.c]
2026-05-22 lcd: Initial commit with minimal usable DMA handling
2026-05-22 bootloader: Fixed SPI handling (a hidden bug that I didn't discover)
    [bootloader.c]
2026-05-24 buzzer: Implemented with volume adjustment mechanism; tim1_pwm: extracted into a dedicated file; chip8: Implemented audio handling and vblank wait handling
    [adc.c, buzzer.c, chip8.h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]
2026-05-29 buzzer: Added another workaround of improper ch32fun definition
    [buzzer.c]
2026-05-29 adc: Exposes card insertion and removal events; Fixed GPIOD configuration handling that it mistakenly modified the NRST and SWIO pin's config
    [adc.c]
2026-05-29 spi/memorycard/lcd: Implemented memory card driver. Also refactored lcd driver so that the SPI can be shared between the memory card and the LCD
2026-05-30 buzzer: fixed click sound on boot by initializing the buffer before kicking off the DMA
    [buzzer.c]
2026-05-30 lcd/spi: Implemented turning off backlight upon accessing the memory card. This is for reducing the peak power usage to make thing with specs of the power supply
2026-06-06 ui: Bugfix on directory navigation: prevents selecting non-existant entries; fixed loading ROM on non-root directory
    [ilomusi8.c]
2026-06-06 file: Moved mounting mechanism from spi module to the file module. Also exposes the f_mount() error in case the card hadn't been initialized properly
    [file.c, spi.c]
2026-06-06 ui: Implemented card error screen
    [ilomusi8.c]
2026-06-07 chip8: audio buffer now uses uint8_t so that all configurable buffer becomes uint8_t. This change also fixes the buzzer audio playback distortion bug
    [chip8.h]
2026-06-11 file: Reduced default buzzer audio frequency from 1000Hz to 500Hz
    [file.c]
2026-06-12 ui: Added legends to game selection menu; Fixed empty screen bug when opening empty directory
    [ilomusi8.c]
2026-06-14 ui: Implemented display of gameplay control of each game; Also removed some redundant anti-tearing handling (because the LCD response time is slow anyway so any tearing won't be visible)
    [file.c, ilomusi8.c]
2026-06-18 ui: Implemented game over screen and game crash screen
    [ilomusi8.c]
2026-06-18 ui: Extracted main loop code into multiple functions naming screen_xxx_handler() to make the purpose of the switch-case in the main loop more obvious
2026-06-19 file: Avoids modifying the FRESULT enum. Instead, extends it
    [file.c, file.h, ilomusi8.c]
2026-06-19 ui: Implemented automatic firwmare verification mechanism on boot. Also delete the firmware file upon successful verification (so that the firmware update won't be performed again in the bootloader)
    [file.c, file.h, ilomusi8.c]
2026-06-20 file: Implemented storage flag saving and loading. Also fixed a storage flag handling bug in the CHIP-8 emulator
    [file.c, file.h, ilomusi8.c]
2026-06-27 file: Added INI config for replay button
2026-06-28 font: added replay button that I missed in the previous commit
2026-06-29 ui: Corrected INI save error handling by directly jumping to the SCREEN_ERROR (instead of going thru the SCREEN_MENU)
    [ilomusi8.c]
2026-07-01 lcd/tim1_pwm: Adjusted PWM frequency and backlight quantization. Now that it's at 400kHz. I've noticed that previous at 3.2Mhz, the backlight could consume more power while the duty cycle's at 50~99%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
2026-07-01 ui: Added low battery handling
2026-07-01 ui: Simplified low battery handling. Instead of having two thresholds, now that there's only one threshold. And it the error won't get resolved until a reboot
    [file.c, file.h, ilomusi8.c]
2026-07-01 adc: Added button debuonce mechanism
2026-07-01 ui: Lengthened the buzzer volume preview duration. Otherwise the preview couldn't be heard because of the louder physical button press sound
    [ilomusi8.c]
2026-07-01 ui: For global config, now that the volume adjustment feedback sound got played regardless if the setting got applied or reverted
    [ilomusi8.c]
2026-07-04 spi/memorycard/lcd/dma: Implemented CRC and SPI DMA for memory card; Also stopped modifying the DMA-related registers while the DMA channel's enabled as recommended by the reference manual
2026-07-04 memorycard: Performance improvement by avoiding excessive waiting
    [diskio.c]
2026-07-04 bootrom: Implemented bootrom mechanism. Also fixed removed chip8_cfg from bulkmem for fixing a memory-sharing bug
    [file.c, file.h]
2026-07-05 ui: Fixed an edge case that upon transition of SCREEN_GAMEPLAY->...->SCREEN_MENU, if button press got detected, the bulkmem->menu_file_list without valid content would get accessed
    [ilomusi8.c]
2026-07-05 ui: Fixed buzzer handling. Previously the volume didn't get applied properly
    [chip8.h, ilomusi8.c]
2026-07-05 ui: Bugfix: Device not accepting input after SCREEN_GAME_CONFIG->SCREEN_MENU transition after a config save
    [ilomusi8.c]
2026-07-05 chip8/file: Implemented audio pitch for game config INI
2026-07-05 ui: Changed menu behavior. Now that after the transition of SCREEN_ERROR->SCREEN_GLOBAL_CONFIG, leaving the global config page would always lead to SCREEN_MENU, which would always cause a rerty of fi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
    [ilomusi8.c]
2026-07-05 ui: Hide the game config legend from menu when a non-game file entry is selected. That's because the button would have no effect in this case
2026-07-11 multilang: Translated error page
    [ilomusi8.c]
2026-07-18 frontlabel: Drawn on-enclosure branding label
2026-07-19 electronics: PCB rev1: Using KiCAD 10; Added silkmark for indicating the buzzer position and polarity of the battery connector; With KiCAD 10, the default SOD-323 footprint pads have been shrunken
    [ilomusiali.kicad_pcb, ilomusiali.kicad_sch]
2026-07-20 electronics: PCB rev1: Added schematics PDF. Changed MCU from CH32V006F8U6 to CH32V006F8U7
    [ilomusiali.kicad_pcb, ilomusiali.kicad_sch]
2026-08-09 ui: Fixed a BOOTROM edge case of button X being held upon boot
    [ilomusi8.c]
2026-08-22 documentation: Added assembly instruction; Added production method documentation for PCBA
    [full_bom.csv]
2026-08-22 documentation: Added README for enclosure
2026-08-24 documentation: Added hardware testing instruction for assembly README file
2026-08-25 documentation: Added full_bom.csv
    [full_bom.csv]
2026-08-30 documentation: Updated a BOM link
    [full_bom.csv]
2026-09-05 documentation: Added packing instruction inside assembly instruction
2026-09-05 documentation: Translated assembly instruction into English
